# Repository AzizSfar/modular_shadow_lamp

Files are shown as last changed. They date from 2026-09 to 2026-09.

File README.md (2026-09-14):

# Modular shadow lamp

A wall lamp with a cylindrical or rectangular SVG-controlled optical sidewall, hollow LED pillar, removable cover, keyed stacking joints and a geometric wall-projection preview. The original default remains a 100 mm diameter, **30 mm closed-depth** cylinder.

**Start with `modular_shadow_lamp.scad`.** It contains an original sunburst demo and needs no external library. All dimensions are in millimetres. `OPTICS.md` contains the derivation, assumptions and limits.

## Try it in MakerWorld

1. Open [MakerWorld Parametric Model Maker](https://makerworld.com/en/makerlab/parametricModelMaker) and load the SCAD source.
2. Generate the built-in demo first. Default dimensions are diameter **100**, closed height **30**, shadow length **300**.
3. Choose **Projection** to see the ideal wall footprint, **Assembly** for the body and exploded cover, or **Diagnostics** for the numerical result.
4. To use your own SVG directly, set **Artwork_source = SVG file**, upload through **Svg_file**, and set **Svg_long_axis** to the longer *drawn artwork* axis. `resize()` normalises whichever axis you declare, so naming the shorter one scales the artwork up until the other axis overshoots the envelope every optical estimate assumes. A direct import is therefore **clamped to a `Shadow_length` square**: a correct declaration already fits and nothing changes, a wrong one is cropped on two sides with a straight edge. That crop is the symptom to look for, and Diagnostics states the clamp on screen. Monza is taller than wide, so `Y` is right — with `X` it would reach a 298 mm radius against a declared 212 mm, a 38% understatement that would make the feasibility numbers meaningless. The other dimension scales proportionally. The requested length is the full artwork's longest dimension before obstruction. The report and console identify the active artwork source.
5. Set **Smallest_detail_percent** to the smallest line or gap you need to preserve. Example: a 6 mm important detail in a 300 mm image is **2%**. Also enter your LED's effective emitting-area dimensions. These quantities materially affect feasibility.
6. Export **Body** and **Cover** separately, or use **Print layout**. Assembly, Projection and Diagnostics contain display geometry and are **not print exports**.

The `Svg_file = "default.svg";` file control follows [Bambu Lab's documented SVG-upload convention](https://forum.bambulab.com/t/paramatric-model-maker-v0-8-0-support-uploading-files/91853). The generator was rendered and tested locally with OpenSCAD 2021.01; its execution in your MakerWorld account has not been tested.

## Run locally — no MakerWorld required

On this computer, OpenSCAD is already available in `tools/openscad-2021.01/`.

- Double-click **Open lamp locally.cmd** to open the main generator in OpenSCAD.
- Double-click **Open SVG locally.cmd** to choose an SVG. It measures and embeds the artwork automatically, saves a fresh local SCAD file in `output/`, and opens it in OpenSCAD. This quick route skips the slow mesh preflight; run the full helper before printing.

In OpenSCAD, use its **Customizer** panel for dimensions and the **Output** selector. Use **Preview (F5)** after changes. For an STL, select **Body** or **Cover**, use **Render (F6)**, then export STL. If the preview reports an impossible combination, use the printed suggestions to adjust the dimensions.

To load an SVG directly without the helper, select **Artwork_source = SVG file**, enter its full path in **Svg_file** (forward slashes, for example `C:/Users/Aziz/Documents/design.svg`), and select the longer axis. **Automatic** mode recognizes changed file paths, while **SVG file** forces import even if the file is named `default.svg`. **Built-in demo** explicitly restores the sunburst.

The old generator needed `Use_svg = true`; uploading a file by itself could leave the demo selected. Its prepared examples also gave embedded artwork unconditional priority. The new selector fixes both cases and prevents old embedded support bridges from being applied to a replacement SVG. Reload the updated SCAD in MakerWorld to get the new controls.

The launcher needs Python 3 and OpenSCAD; both are already present here. On another computer, install OpenSCAD first. The helper's direct command also works locally:

```powershell
python run_local.py --svg "C:/path/to/artwork.svg"
```

## Automatic SVG preparation — recommended

For the Itachi and Monza reference investigation, see `DESIGN_REVIEW.md`. New
preparation controls and the dimension comparison tool are described below.

OpenSCAD imports SVG geometry but does not expose its dimensions, smallest feature or connected components to its scripting language. Consequently, direct MakerWorld mode requires the longer-axis selection and a declared minimum detail, and uses a conservative square envelope. **A pass in direct mode is not a complete SVG printability certificate.**

The included `prepare_svg.py` helper uses OpenSCAD itself to interpret the SVG, then:

- finds the actual drawn bounds and preserves the aspect ratio automatically;
- calculates a tighter outer-radius bound from the resulting polygons;
- embeds the artwork into a **single SCAD file** that can be uploaded to MakerWorld;
- checks the optical limits, exports the actual body mesh, and checks its edge closure and connectivity;
- adds short vertical ribs underneath disconnected stencil islands, rerenders and checks again;
- produces a checked body STL, cover STL and JSON report when successful.

From this project folder:

```powershell
python prepare_svg.py "C:/path/to/artwork.svg" --length 300 --diameter 100 --height 30 --detail-percent 2 --output output/my_lamp.scad
```

Python 3 and OpenSCAD are required. Default conversion uses the standard library; surface cleanup with `--minimum-web`, the design study and projection comparison also require NumPy and Pillow (already installed here). It finds the portable OpenSCAD in this project, an installed copy, or the executable given with `--openscad`. The distribution ZIP does not bundle OpenSCAD; [download it here](https://openscad.org/downloads.html) if needed.

The result is self-contained: upload `output/my_lamp.scad`. **Automatic** initially selects its embedded artwork. To replace it, select **Artwork_source = SVG file** and upload another SVG, or rerun the helper for automatic sizing and mesh checks. Dimension, source and support settings remain customizable. **Changing them after preflight invalidates the old mesh-check result; rerun the helper before printing the changed design.**

Try `examples/two_rings.svg` to exercise disconnected-island detection:

```powershell
python prepare_svg.py examples/two_rings.svg --output output/two_rings_lamp.scad
```

Use `--dark-silhouette` for filled SVG areas to remain dark within a circular lit field. By default, filled SVG areas become **light**, matching the luminous contour effect in the reference photograph. Convert strokes and text to paths, remove bitmap images and unwanted background rectangles, and inspect the imported result. OpenSCAD supports geometric SVG, not every SVG rendering effect; see its [SVG import documentation](https://files.openscad.org/documentation/manual/SVG_Import.html).

The helper deliberately does **not** invent a smallest-detail measurement: pointed corners mathematically taper to zero, and a minimum edge length is not a stroke width. `--detail-percent` is the detail you actually require. Automated bridges can change the appearance; inspect Projection after preparation.

## Reference preparation, fragile webs and housing shape

`Housing_shape = "Rectangle"` switches the body, cover, joints, standoff and wall
footprint together. `Rectangle_width` and `Rectangle_depth` are the two outer XY
dimensions. `Cylinder_height` remains the closed optical-module depth for either
shape. The wire pillar and its bore remain circular. Matching parts must share
the shape and both XY dimensions.

Use this preparation route for the supplied references:

```powershell
python prepare_svg.py itachi_example.svg --length 800 --diameter 80 --height 44 --wall-standoff 10 --minimum-web 0.6 --bridge-width 0.9 --automatic-bridges-only --output output/itachi_final.scad
python prepare_svg.py monza_example.svg --length 600 --diameter 80 --height 36 --wall-standoff 10 --minimum-web 0.6 --bridge-width 0.9 --automatic-bridges-only --output output/monza_final.scad
python prepare_svg.py monza_example.svg --shape Rectangle --rectangle-width 80 --rectangle-depth 80 --length 600 --height 36 --wall-standoff 10 --minimum-web 0.6 --automatic-bridges-only --output output/monza_rectangle_final.scad
```

These are **comparison prototypes**, using the existing 5% declared-detail
assumption and a 0.2 mm emitting area. Five percent is not a measurement of either
SVG's fine details. The new small-aperture screen reports features the 0.4 mm
filter flags; neither a broad optical pass nor mesh closure certifies that every
aperture will survive slicing with a 0.4 mm nozzle.

- `--automatic-bridges-only` starts without the twelve regular spokes. Mesh
  preflight adds vertical ribs only where needed and stops them inside each
  retained island. Projection includes the finite rib shadows.
- `--minimum-web 0.6` simplifies thin **opaque** slivers in developed inner-shell
  coordinates, sampled at about 0.06 mm. Corrections are projected back onto the
  wall and combined with the original vector light geometry. It does not thicken
  every stroke. Detached specks smaller than the width cubed (0.216 mm³ here)
  are removed through their projected footprints; larger islands receive ribs.
- `--bridge-width 0.9` is a starting point for approximately two extrusion lines
  with a 0.4 mm nozzle. Use your slicer's actual line-width settings. Simplification
  may erase dark detail; supports remove light. Check the comparison images.
- `--minimum-web 0` disables surface simplification. The default remains zero
  for compatibility. The native SCAD control uses a more conservative wall-space
  filter when no prepared surface stencil exists; its result is different.
- After changing geometry or artwork placement in a prepared surface file,
  rerun the helper. A stale prepared surface blocks Body/Print layout exports.
  Preview falls back to the native filter and warns; it is not a refreshed preflight.
- STL preflight welds export coincidences at 0.000001 mm and removes triangles
  collapsed by that rounding. This fixes export noise, not real disconnected parts.

Compare dimensions and actual artwork visibility:

```powershell
python compare_designs.py itachi_example.svg monza_example.svg --detail-percent 5 --output output/reference_study_5percent
python compare_designs.py itachi_example.svg monza_example.svg --detail-percent 2
python inspect_projection.py output/itachi_final.scad output/monza_final.scad output/monza_rectangle_final.scad --resolution 5000
```

The bounded study samples 4,320 combinations per reference: housing shape/size,
optical height, standoff, image length and XY placement. It counts the standoff
in **total depth**, and ranks `length / total depth / sqrt(footprint area) × visible
artwork fraction`, with an 85% visibility threshold. This is an explicit trade-off,
not a global optimum. Area retention does not know which parts of a character
are important. The 2% study demonstrates how much stricter detail requirements
can change the answer.

Projection inspection exports original artwork, housing-only clipping, the
modified footprint and an independent projection of the opaque STL. Its JSON
separates hidden artwork, removed light, added light and mesh/preview agreement.
Raster edge coverage affects the last metric, especially on narrow outlines.
Changing a generated source invalidates the stored mesh fingerprint.

## What the LED optimization means

The supported layout is a **concentric image surrounding the lamp**, as in the reference. The source is on the housing axis: **x = 0, y = 0**. This is the minimax position for a circular 360-degree field in the cylinder; the rectangle uses conservative on-axis bounds. The script analytically maximizes z subject to the upper collar, next module, pillar and source clearances. This is not an unrestricted optimizer for an asymmetric picture placed entirely beside the lamp.

The default demo gives:

| Quantity | Result |
|---|---:|
| Closed single-module depth | 30 mm |
| Body diameter | 100 mm |
| Emitting centre above module back | 24 mm |
| Printed pillar top | 21 mm |
| Ideal artwork length | 300 mm |
| Hidden central radius | 64.86 mm |
| Minimum local cut estimate, for declared 15 mm detail | 0.768 mm |
| Geometric source-blur estimate, 0.2 mm planar emitter | 0.425 mm |

The 0.2 mm emitter is an **optical assumption**, not a supplied or selected LED. Use the apparent emitting area seen through the side apertures; a domed lens may change it. A normal large or diffused LED may fail the sharpness limit. Zero source depth assumes a planar emitter parallel to the room wall. The LED must actually emit into the rays directed sideways and back toward the wall; a narrow forward-facing beam will not reproduce this preview.

The physical pillar prevents z=0, and the cover/next module prevents z=H. Manual-height mode reports incompatible positions instead of constructing a negative or colliding pedestal.

## Buildable versus worth printing

Two very different things used to share one verdict. They are now separate.

**Hard geometry** — a pillar wider than its cavity, a source below the floor, or an image that falls entirely inside the occluded centre — still refuses. There is nothing to build, and no warning rescues it. Diagnostics says *GENERATION NOT POSSIBLE: the geometry itself cannot be built*.

**Print quality** — the minimum cut width and the maximum blur — no longer blocks anything. The part builds, and Diagnostics reports *BUILDS — BELOW QUALITY LIMITS* in amber with the number that failed:

```
WARNING: this builds, but the smallest cut is 0.114 mm against a 0.4 mm minimum.
Blur is 2.76 mm against a 2 mm maximum. Fine detail will be lost or unprintable.
Try height 37 mm, shadow 363.4 mm.
```

`Quality_limits = "Refuse"` restores the old behaviour if you would rather be stopped. The helper carries the warning into its JSON report as `quality_warnings` and marks the validation string `BELOW QUALITY LIMITS`, so a preflight run tells you without refusing on your behalf.

This is a real choice, not a loosened check. A 0.114 mm slot will not print on a 0.4 mm nozzle — the detail closes up and you get a blob. The generator now assumes you would rather see the result and judge it yourself.

## Why some requests fail

“30 mm deep and a 1 m image” is not intrinsically impossible. It depends on diameter, feature size, source extent and image placement. Height alone cannot fix blur from a source that is too wide.

For example, with the **direct-SVG square envelope**, 100 mm diameter, 30 mm height, 1,000 mm length, 5% detail, 0.4 mm minimum cuts, 0.2 mm planar emitter and 2 mm maximum blur, the requirements fail. Diagnostics shows:

- an alternative shadow length at the same height;
- an alternative height at the same length, if one exists;
- a compromise minimizing the sum of the squared *relative* height and length changes.

The compromise searches larger heights in 1 mm steps up to the displayed limit (at most 300 mm), with a binary search for shadow length at each height. These are **nearest sampled alternatives under that stated metric**, not a claim of the globally closest dimensions. A conservative direct-import failure may disappear after the helper measures the actual SVG envelope. Suggested results do not establish brightness or physical printability.

For that example, the calculated compromise is **37 mm height / 371.9 mm shadow**. Keeping 30 mm height gives **287.9 mm shadow**. No tested height preserves the 1,000 mm request with the assumed emitter and 2 mm blur limit. Direct SVG mode's conservative bound also means a 300 mm request with the default 5% detail narrowly fails; start at **280 mm** or use the helper's tighter artwork measurement.

For the prepared **two-ring SVG**, the actual outer radius is smaller than the square bound. Requesting the same 1,000 mm length at 30 mm depth instead gives a **36 mm / 719.9 mm** compromise, **575.9 mm** at the original height, or **48 mm height** to retain the full 1,000 mm length under the selected optical limits. These are optical suggestions; rerun mesh preflight at the chosen dimensions.

## Cover, mounting and stacking

The wall is the XY plane at z=0; positive z points into the room. The wall-facing back has two keyholes with 7 mm head entries, 3.5 mm shaft slots and 5 mm upward slots. With the screw heads through the larger entries, slide the lamp downward to engage the narrow slots. Use a fastener and wall fixing appropriate to the actual wall and load.

The back is 4.5 mm thick, with a recessed keyed female socket. The front has the matching male tongue. The cover carries the same female socket. The default fit has **0.2 mm radial clearance** and **0.2 mm axial clearance**. This is a locating slip fit; use the three optional retaining screws when a positive hold is needed. The pilot-hole diameter is 2.1 mm; select and test compatible short screws. The fit and screw choice have not been physically tested.

The closed 30 mm assembly includes a 4.5 mm cover. Remove it and seat the next cylinder onto the tongue. Each added module increases the depth by **25.5 mm**. Two modules plus one final cover are 55.5 mm deep. Keep diameter, wall, joint and cover dimensions the same across a stack.

Generate each optical cylinder for its own **Module_index**: 0 at the wall, 1 next, and so forth. Every optical module needs its own LED at its own calculated height. The solid rear floor separates the modules. Moving a cylinder farther from the wall without regenerating it changes its projection. The central obscured area grows for farther modules; increasing the target length may be necessary. Stack preview displays the selected module's light and simplified lower-module envelopes, not a summed multi-LED lighting simulation.

The pillar contains a wire bore and terminates 3 mm below the nominal emitting centre. It is a generic mounting land, not a fit for an unspecified LED package. Attach an LED carrier whose **optical centre** has the stated offset. Larger boards, wiring, screw heads or electronics entering the optical rays can create additional shadows. The cover opens the electronics compartment; electrical design, heatsinking and thermal testing remain to be done with the actual hardware. Keep retaining holes occupied or plugged during optical tests.

## Wall standoff and the electronics compartment

`Wall_standoff` is the clear gap held between the room wall and this module's back. **0 is flush to the wall and reproduces the previous geometry exactly.** The gap is a closed compartment with the keyholes and cable route on its own back plate, whose thickness is `Standoff_back`.

- **Separate ring** (`Output = "Standoff"`) prints the gap as its own part, driving the same keyed tongue into the body's existing rear socket. Change the standoff without reprinting the optical body. Needs `Wall_standoff >= Standoff_back`.
- **Extended body** grows the body backwards instead: one part, no extra joint, but any change means reprinting the whole optical body.

Optically, a standoff is identical to mounting the module further into the room. Every mechanical plane translates with it, so the source rises by exactly the standoff and radial resolution improves in direct proportion. **It is not free.** `rho_dead = R*h/(h-A)` has both `h` and `A` rising together, so the hidden centre widens at a similar rate:

| Standoff | Source height | Cut estimate | Hidden radius |
|---:|---:|---:|---:|
| 0 mm | 24 mm | 0.768 mm | 64.9 mm |
| 20 mm | 44 mm | 1.408 mm | 118.9 mm |
| 50 mm | 74 mm | 2.368 mm | 200.0 mm |

So a standoff pays off only if the image grows with it. On the default 100 × 30 mm module, 50 mm of standoff **rejects** a 300 mm image — the 200 mm dead radius swallows it — while projecting 600 mm comfortably at a 1.184 mm cut estimate. Flush, the same lamp cannot reach 600 mm at all and manages 300 mm at 0.768 mm. Read the Diagnostics suggestion when it refuses.

From the helper:

```powershell
python prepare_svg.py artwork.svg --wall-standoff 25 --length 500 --output output/my_lamp.scad
```

The ring is mesh-checked alongside the body and cover and written to `<name>_standoff.stl`.

The compartment is a void with a cable route, nothing more. Electrical design, insulation, driver placement, clearances and heat inside it are yours to work out, and none of it has been tested.

## Bounding the light in dark silhouette

By default a dark silhouette sits in a lit disc that reaches the whole beam radius. **Light limit** replaces that disc with a band of chosen width hugging the shadow; past the band the wall goes dark again.

```
Artwork_mode          = "Dark silhouette";
Light_limit           = true;
Light_limit_shape     = "Same as shadow";   // or Circle, Rectangle
Light_limit_thickness = 25;                 // band width on the WALL, mm
```

- **Same as shadow** follows the outline, offset outwards by the thickness. Corners come out rounded at the band radius; a mitred outset would spike at acute corners into slivers too fine to print.
- **Circle** wraps the artwork's bounding circle. Note this is *larger* than the unlimited disc whenever the thickness exceeds `Dark_field_border`, so it is a way to size the lit disc explicitly rather than a way to shrink it.
- **Rectangle** wraps the artwork's true bounding box, and turns with `Artwork_rotation` so it stays tight. The real proportions can only be measured by the helper — a directly imported SVG falls back to a square, which for a tall or wide design lights a lot of empty wall. A rectangle also reaches furthest at its **corners**, so its optical envelope is `sqrt(2)` times a circle of the same half-width and it fails the feasibility test sooner.

From the helper:

```powershell
python prepare_svg.py artwork.svg --dark-silhouette --light-limit --light-limit-thickness 22 --light-limit-shape "Same as shadow" --output output/my_lamp.scad
```

### Which side of the artwork gets bounded

`offset()` moves every boundary at once, so on a closed outline — a circuit map, a monogram, any loop — it eats the enclosed interior as well as bounding the outside. The two sides are therefore separate switches:

```
Light_limit_outside = true;   // bound the light outside the artwork's silhouette
Light_limit_inside  = false;  // leave an enclosed interior fully lit
```

For a circuit map that combination is almost always what you want: a band tracing the outside of the track, and the whole infield lit. All four combinations are legal — `outside off / inside on` lights the entire beam except a ring inside the loop, which is the inverse effect.

**`Light_limit_inside` works on any artwork, with nothing else to configure.** Splitting the field needs to know which enclosed areas are interior. Prepared artwork carries a measured silhouette; a direct import — including every MakerWorld upload, where the helper cannot run — has none, so the interior is found by closing anything narrower than `Interior_span`.

`Interior_span = 0` means **automatic, and automatic is `Shadow_length`**. An enclosed area cannot be wider than the artwork that encloses it, so that is the one value which can never under-fill. Set a smaller number only if you want a tighter result: too small silently finds nothing, which is the failure this default exists to prevent. Diagnostics names the method — measured silhouette, or closed at N mm, marked *(automatic)* or *(set)* — so you never have to guess whether it took effect.

Artwork prepared by the helper needs none of that: it carries a measured **silhouette** and ignores `Interior_span` entirely. Telling a hole from the outside needs the artwork's **silhouette** — its outermost contours with every hole filled. Only the helper can work that out, by testing the nesting depth of each flattened contour, so it writes the silhouette into the file as separate geometry. A directly uploaded SVG has none, and the generator then applies one setting to both sides and echoes a note saying why. Use `--light-limit-inside off` / `--light-limit-outside off` on the helper.

### Two things the band does to you

**A thin band is a thin slot.** Unlike `Smallest_detail_percent`, which you declare, the band width is a feature the generator knows exactly, so it reports the slot the band opens in the shell and warns when that falls under `Minimum_cut_width`. Flush, 300 mm image:

| Band | Slot in the shell |
|---:|---|
| 5 mm | 0.240 mm — warned |
| 10 mm | 0.450 mm |
| 25 mm | 0.940 mm |
| 50 mm | 1.440 mm |

The minimum that clears a 0.4 mm slot is **8.8 mm** flush at 300 mm, **4.5 mm** with a 20 mm standoff, **10.9 mm** at 50 mm standoff / 600 mm — roughly 2–3% of image length, and a standoff nearly halves it. A band under the limit still builds, with the warning and the suggested width in Diagnostics, so you can preview something you know is too fine to print.

**A closed band strands whatever it encircles.** Every shape inside a loop of light is disconnected from the frame. This is not new — an unlimited dark silhouette does exactly the same, and the mesh preflight measures the identical component count either way — but it means `Support_bridges` or the helper's automatic ribs must stay on, and their lines will cross the band. A narrower band means shorter, less obtrusive bridges.

One behaviour worth watching: widening the band fuses the halos of nearby shapes into one. On `two_rings` at 160 mm, 3/8/20 mm bands keep four separate lit regions and a 40 mm band drops to three. Nothing warns about this — inspect Projection after changing the thickness.

## Print and physical test

Print the body with its flat rear face on the bed. The Cover output is already flipped with its solid face on the bed. Preview the sloped apertures and small underside socket bridges in your slicer; support requirements depend on the artwork and printer. Use opaque material and remove any support that blocks the optical tunnels. Print a joint-fit sample or check the first module before producing a stack.

First test at the calculated LED position on a wall in a dark room. Measure image length, adjust the source to the *emitting centre*, and compare detail sharpness. The preview is an ideal geometric light footprint, not a prediction of brightness, colour, scattering, lens effects or diffraction. The lamp inevitably hides the centre; no sidewall pattern can recover artwork behind its opaque body. Narrow connecting bridges also cast dark lines. Exact reproduction of an arbitrary, unmodified SVG is therefore not always physically possible with this architecture.

## Validation supplied

`output/validation.json` records checks on the default exported body and cover. Both have one connected surface component and every mesh edge belongs to two triangles. An independent perspective projection of the opaque STL triangles agrees with the analytic footprint with intersection-over-union **0.9864** at 2,000 × 2,000 pixels over a 360 mm wall field. Raster edge coverage accounts for much of the residual difference; this is not a physical optical test.

`tests/test_optics.py` checks inverse/forward ray mapping through both shell radii, finite-difference surface compression and source blur, stacked-module offsets, invalid source cases and a suggested dimension pair. `tests/verify_mesh_projection.py` additionally requires NumPy and Pillow. The helper's SVG test checks the exported stencil and adds two retaining bridges to the supplied two-ring example.

`tests/check_joint_fit.py` checks the actual body against a seated cover, a following body, and a seated standoff ring. All three intersections are empty after a 0.01 mm separation to exclude intended coplanar seating contact; the default parts have no positive-volume interference in this test.

`tests/test_light_limit.py` covers the light limit: that switching it off changes nothing, that a band lights less wall than the unlimited disc, that the band is exactly the artwork grown by the thickness minus the artwork, that each shape reaches as far as its geometry predicts and a rectangle's envelope uses its corner rather than its side, that the reported slot scales with the band and the suggested minimum really clears the limit, that a band too fine to print warns and still builds, and that the band strands exactly the same number of islands as the unlimited disc already did.

`tests/test_standoff.py` covers the standoff against real rendered meshes: that the source rises by exactly the standoff while the local height is untouched, that sharper detail and a wider hidden centre move together across 0/20/50 mm, that 600 mm is reachable at 50 mm of standoff and not at 0, that 50 mm of standoff correctly *refuses* a 300 mm image, that a zero standoff leaves the body identical, that the ring and both body modes are single closed solids sitting on the bed, and that the compartment is a vented shell rather than a sealed cavity. A ring thinner than its own back plate, and a Standoff export with no ring configured, are checked to fail loudly.

No physical lamp has been printed or illuminated yet. Mesh closure does not prove minimum ligament thickness, support-free printing, mechanical strength, thermal performance or an exact match to the photograph.

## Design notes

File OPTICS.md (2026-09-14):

# Projection geometry and optimization

All distances below are millimetres. These equations are derived for straight rays, an opaque cylinder and a point source. Finite-source estimates are a first-order extension; the display itself uses the point-source footprint.

## 1. Coordinate system and the inverse construction

The room wall is z=0. The cylinder axis is normal to it. Let the source be S=(0,0,h), with h measured **from the room wall**, and let a desired lit wall point be P=(x,y,0), with radial distance rho=sqrt(x²+y²).

The complete ray is

```
Q(t) = S + t(P-S),       0 <= t <= 1.
```

At a cylindrical surface of radius r, t=r/rho. Therefore:

```
Q_r(P) = (r*x/rho, r*y/rho, h*(1-r/rho)).
z_r    = h*(1-r/rho).
```

The outer surface is crossed at z_o=h(1-R/rho), and the inner surface at z_i=h(1-R_i/rho). Since R_i<R, z_i>z_o. **The inner and outer openings must be at different heights.** Simply wrapping the SVG around the cylinder, or making straight radial holes, does not implement the correct projection through a thick shell.

The forward check is:

```
P_xy = h/(h-z) * Q_xy.
rho  = h*r/(h-z).
```

For every filled 2D target point, `linear_extrude()` with a linearly decreasing scale sweeps precisely this ray. The script subtracts that entire perspective cone from the shell. It ends the cone 0.05 mm below the source, with scale 0.05/h, avoiding a degenerate apex while leaving the optical shell intersections unchanged. All valid source clearances keep the shell crossings below that truncated tip.

The approach uses OpenSCAD's [linear extrusion with scale](https://files.openscad.org/documentation/manual/OpenSCAD_User_Manual.pdf) and [SVG geometry import](https://files.openscad.org/documentation/manual/SVG_Import.html). The equations and feasibility policy here are specific to this project.

## 2. Mechanical planes and the hidden centre

Let H be one closed module's depth, J the tongue insertion depth, T the cover plate thickness and p=H-J-T the stacking pitch. For module n:

```
z0 = S + n*p                     module back's distance from wall
A  = z0 + rear_floor + rear_guard lower optical opening limit
B  = z0 + p - front_guard         upper optical opening limit
R_f = R - frame_width            thick front collar's inner radius
```

S is the wall standoff: the clear gap held between the room wall and module 0's back,
by a separate spacer ring or by an extended rear skirt on the body. It enters every plane
above, so optically a standoff is indistinguishable from mounting the same module that
much further into the room.

A ray must cross the outer radius above A. Thus

```
h*(1-R/rho) >= A
rho >= R*h/(h-A),                 with h>A.
```

This is larger than R: the rear plate and uncut structural rim hide more than just the visible body diameter.

The pillar is modelled as a cylinder of radius r_p ending e below the emitting centre. Its upper edge creates another central shadow:

```
rho_pillar = r_p*h/e.
rho_dead   = max(R*h/(h-A), r_p*h/e).
```

Both expressions use **absolute h**, including the stacking offset. They explain why farther modules hide a larger central portion of the wall. The source cannot be put on the wall plane: the forward mapping degenerates at h=0 and the hardware occupies that space.

If h>B, the front collar sets an outer reach:

```
rho <= R_f*h/(h-B).
```

If h<=B, this upper-collar limit is absent because all rays heading toward the wall are below the collar. The sidewall's upper opening gives the same form with R_i; R_f is smaller and therefore more restrictive in this design.

The displayed light is the intended 2D transmitting region intersected with this reachable annulus, minus the radial support wedges. The cylinder itself overlays the central body disk in the display. Mounting holes sit behind that disk; other electronics are not represented as occluders.

## 3. Why x=y=0 for the supported layout

The objective is to maximize the **worst local reproduction scale over a complete concentric 360-degree field**, not to fit a spotlight image displaced to one side. The pillar moves with the source in the hypothetical comparison, and the housing remains concentric.

For a lateral displacement d, look at the two wall directions parallel and opposite to the displacement at the same radius rho. The radial stretch coefficients are proportional to:

```
g_near = (R_i-d)/(rho-d)^2
g_far  = (R_i+d)/(rho+d)^2
g_axis = R_i/rho^2.
```

For both displaced coefficients to exceed g_axis would require both

```
rho*(2*R_i-rho) > R_i*d
rho*(rho-2*R_i) > R_i*d,
```

which is impossible for d>0. At least one radial direction gets worse. The tangential stretch toward the nearer side, (R_i-d)/(rho-d), is also smaller than R_i/rho when rho>R_i. Therefore a displaced source cannot improve the worst of the radial and tangential stretches around the full circle at fixed h. The nearest-side upper-collar clearance also cannot allow a larger h than the concentric source, and the mechanical ceiling is unchanged.

This establishes the on-axis minimax choice for that symmetric field. An asymmetric SVG occupying only a restricted angular sector could benefit from an off-axis source. Such an artwork-specific, unrestricted optimization is **outside this generator's scope**; setting x and y to zero must not be interpreted as having performed it.

## 4. Height optimization

Let rho_max=k*L bound the artwork, where L is its longest dimension. Direct SVG mode uses k=sqrt(2)/2, which bounds a centred square of side L. The helper evaluates k=max(sqrt(x_i²+y_i²)) over the normalized polygon vertices. A convex norm attains its maximum on each straight polygon edge at an endpoint, so this is a valid bound for OpenSCAD's flattened geometry. The demo has k=1/2.

The source must clear the **back of a possible next module**, rather than borrowing cavity space inside the removable cover:

```
h_ceiling = z0 + p - 1.5.
```

To reach rho_max through the front collar:

```
h <= B/(1-R_f/rho_max),           when rho_max>R_f.
```

To leave at least some possible artwork beyond the pillar shadow along the longest dimension:

```
h <= e*(L/2 - minimum_cut - epsilon)/r_p.
```

The selected h is the minimum of those upper bounds. The code subsequently checks the lower hardware and rear-rim clearances. Within these constraints, larger h increases radial aperture size, improves axial-source blur and reduces the rear-rim shadow. The explicit pillar constraint prevents increasing h until its shadow swallows the whole field.

This maximizes the local resolution estimate for the supported field. It is not an optimization of total luminous flux, subjective image quality, occluded image area or manufacturing cost. If the SVG has no filled region in the reachable annulus, the envelope test alone cannot detect that; the helper's geometry/mesh inspection and the preview remain necessary.

## 5. How detail compresses onto the shell

Parameterize the inner shell by arc length s=R_i*theta and height z=h(1-R_i/rho). A tangential wall displacement rho*dtheta becomes R_i*dtheta, and a radial displacement d(rho) becomes (h*R_i/rho²)*d(rho). The local scale factors are:

```
sigma_t = R_i/rho
sigma_r = h*R_i/rho^2
sigma_min = min(sigma_t, sigma_r).
```

For a declared important wall detail f=alpha*L, use the conservative outer-radius estimate:

```
w_estimate = f * min(R_i/rho_max, h*R_i/rho_max^2).
```

The radial direction is often much worse than the tangential one. At constant fractional detail alpha and envelope k, radial cut size varies approximately as h/L. Merely making the requested wall image bigger does not make it easier to print.

For h=24, R_i=48, rho_max=150 and f=15, the estimate is 0.768 mm. For the direct square bound of a 1,000 mm image, rho_max=707.107 and f=50, it is about 0.115 mm: below a selected 0.4 mm cut limit.

### 5a. What a standoff buys, and what it costs

Raising the module by S raises the admissible source height by very nearly S: the collar
constraint h = B/(1-R_f/rho_max) is linear in B, and B grows with S. sigma_r = h*R_i/rho_max^2
is linear in h, so radial resolution improves in direct proportion.

The hidden centre moves the other way. In rho_dead = R*h/(h-A) both h and A grow by S, so the
numerator grows while the denominator barely moves and the occluded disc widens roughly
linearly in S. Measured on the default 100 x 30 mm module at L=300:

| Standoff S | Source h | Cut estimate | Hidden radius |
|---:|---:|---:|---:|
| 0 mm | 24 mm | 0.768 mm | 64.9 mm |
| 20 mm | 44 mm | 1.408 mm | 118.9 mm |
| 50 mm | 74 mm | 2.368 mm | 200.0 mm |

A standoff therefore does not simply make images bigger: it trades a wider dead centre for
sharper detail, a net gain only if the image grows with it. At S=50 the feasibility test
L/2 > rho_dead + w_min fails outright for L=300, while L=600 passes with a 1.184 mm cut
estimate -- a length the flush module cannot reach at all.

This is a **local first-order feature estimate**, not an exact minimum-thickness computation on every curve, ligament or oblique channel. Sharp tips naturally approach zero width. What counts as an important feature must be specified by the designer. The helper detects disconnected components but does not certify every ligament's width or printer capability.

### 5c. A bounded lit field

A dark silhouette normally subtracts the artwork from a disc of radius k*L + border. The
light limit replaces that disc with a bounded region D, so the lit field is D minus the
artwork. Three choices of D:

```
Same as shadow:  D = artwork (+) disk(T)        rho_max = k*L + T
Circle:          D = disk(k*L + T)              rho_max = k*L + T
Rectangle:       D = box(w*L/2 + T, h*L/2 + T)  rho_max = hypot(w*L/2 + T, h*L/2 + T)
```

where (+) is Minkowski addition, w and h are the artwork's extents as fractions of its
longest side, and T is the band width on the wall. The rectangle reaches furthest at its
corner, which is what rho_max must use; taking its half-width instead understates the
envelope by up to sqrt(2) and lets an infeasible request pass.

The band width is the one wall feature whose size is known rather than declared, so its
slot in the shell follows directly from section 5:

```
w_band = T * min(R_i/rho_max, h*R_i/rho_max^2).
```

Since rho_max itself contains T, the thinnest band that still opens a w_min slot has no
closed form; the generator settles it by repeated substitution. At h=24, R_i=48, k=0.5 and
L=300 the fixed point is T = 8.8 mm for w_min = 0.4 mm. A standoff raises h and so lowers
that floor: 4.5 mm at S=20.

### 5d. Bounding one side of a closed outline

Minkowski addition moves every boundary of A outwards, which for a hole means inwards. On a
closed outline the enclosed interior is a hole, so `A (+) disk(T)` shrinks it by T and the
interior goes dark. Bounding the outside without touching the inside needs the silhouette

```
F = fill(A),   A's outermost contours with every hole filled,
```

and then the field splits at F:

```
outside = (disk(beam) - F)  intersect  (bounded ? D : everything)
inside  = F                 intersect  (bounded ? A (+) disk(T) : everything)
D_total = outside union inside,     lit = D_total - A.
```

All four on/off combinations fall out of this, and both switches off reproduce the plain
dark silhouette exactly. fill(A) is not obtainable from A by morphology -- a closing fills
holes only up to its own radius and rounds everything else on the way -- so it comes from
contour topology instead: flatten the SVG, count how many contours of the same path contain
each contour, and keep those at even-odd depth zero. That is a property of the path data, not
of the rendered region, so it is available to the preparation helper and not to `import()`.

When the silhouette cannot be measured -- a direct `import()`, and so every MakerWorld
upload -- fill(A) is approximated by a morphological closing with a mitred structuring
element of half-width S:

```
fill(A) ~= erode(dilate(A, S), S).
```

Dilation followed by erosion returns a convex boundary to where it started and closes any
enclosed area or concave pocket narrower than 2S, so the error is confined to outer pockets
narrower than the span. Measured against the exact silhouette of the Monza outline at
L=300 mm, where the true fill is 19,304 mm^2:

| S | closing | missing | extra | error |
|---:|---:|---:|---:|---:|
| 40 mm | 7,800 | 11,573 | 69 | 60.3% |
| 60 mm | 19,420 | 2 | 117 | 0.62% |
| 120 mm | 19,509 | 3 | 208 | 1.10% |
| 200 mm | 19,308 | 141 | 144 | 1.48% |
| 450 mm | 21,882 | 8 | 2,586 | 13.4% |

The usable window is broad: anything from just over half the enclosed width up to roughly the
artwork's own length agrees with the exact silhouette to within about 1.5%. Below that it
under-fills sharply, and far above it the result drifts toward the convex hull, which for this
outline is 28,628 mm^2. Rounded joins were rejected: `offset(r=)` pulls the outer boundary in
during erosion, whereas mitred joins restore it exactly.

The construction says nothing about connectivity. D minus artwork is an annular region
whenever the artwork lies inside D, so every enclosed shape is a separate component of the
opaque stencil. That is already true of the unbounded disc and is not made worse here, but
it is structural rather than incidental: no choice of T avoids it.

## 6. Finite LED size and blur

At a fixed aperture point (Q_xy,z), the wall point from a source with transverse location S_xy is

```
P_xy = S_xy + h/(h-z)*(Q_xy-S_xy).
M = h/(h-z) = rho/R_i.
```

Differentiate with respect to the source position while holding the aperture fixed:

```
|dP/dS_xy| = M-1
|dP/dh|   = (M-1)*rho/h.
```

For effective transverse source diameter d_xy and axial extent d_z, the sum

```
b_estimate = (rho_max/R_i - 1) * (d_xy + d_z*rho_max/h)
```

is a conservative first-order extent estimate. Axial thickness is especially costly at grazing angles. With a planar source, transverse blur is independent of h at fixed cylinder and image radii: a taller cylinder alone cannot fix an overly wide source. Lens optics, angular emission, vignetting, scattering and diffraction are not simulated. A finite source also shifts the effective aperture visibility, so this scalar estimate is not a rendered penumbra.

For illustration, an isotropic point source of radiant intensity I produces wall irradiance

```
E(rho) = I*h/(rho^2+h^2)^(3/2).
```

The extra cosine factor from the grazing wall angle means far-wall brightness falls approximately as rho^-3 in this shallow geometry. A wall-facing Lambertian emitter adds another cosine factor. Without the LED's angular intensity distribution and power, the script cannot infer usable brightness or exposure.

## 7. Feasibility and closest alternatives

The solver requires valid mechanical dimensions, a valid source position, some potential field outside the central obstruction, the local cut estimate above the chosen threshold, and estimated blur below the chosen maximum. It does not invent a universal maximum image size from cylinder height alone.

On failure in automatic mode, it searches H upward in 1 mm steps to min(300,max(160,3*H_requested)). At each height it finds the largest qualifying L no greater than the requested length, using a binary search on the monotone quality limits, followed by the mechanical/visible-field checks. It rounds L downward to 0.1 mm. Candidate pairs minimize

```
cost = ((H-H_requested)/H_requested)^2
     + ((L-L_requested)/L_requested)^2.
```

Equal relative changes have equal weight. The script additionally reports holding the requested H fixed or holding L fixed. If no candidate exists, it states that the selected search range/assumptions have no solution and suggests changing diameter, required detail or source extent. It does not label that as a proof of physical impossibility under all possible designs.

## 8. Structural and optical compromises

Closed luminous outlines can leave opaque material floating inside an opening. Fixed spokes cannot retain every arbitrary island. The helper exports the real body and identifies disconnected surface components. It now places vertical ribs under the lowest face of each substantial floating component, stopping inside the island. With surface cleanup enabled, detached specks below `Minimum_web_width^3` cubic millimetres are removed through their projected convex footprints and recorded explicitly in the JSON. It rerenders and checks again, up to eight attempts. Unresolved failures are reported.

Connectivity does not establish ligament strength or physical printability. Bridges necessarily alter the original light pattern. A fully exact SVG containing floating opaque islands needs another support architecture, such as a separate transparent mask substrate, and cannot be promised by a single-material carved shell.

Stacking adds an absolute offset to every ray calculation. Equal-diameter lower modules are behind the current module's rear plate and within its central occlusion envelope. Larger lower modules, external brackets, exposed electronics and light leakage through open cable/screw holes require additional occlusion modelling. Generate each equal-diameter module for its own index and use independent, properly shielded sources.

## 9. Rectangular housing and bounded design study

The cone remains `P(t) = (t*x, t*y, h*(1-t))`; only the housing intersection
changes. For a face at X=a, a wall point (x,y) maps to `(a, a*y/x, h*(1-a/x))`.
The inverse is the same perspective projection as for the cylinder. Flat faces
introduce shear, so using only radial and tangential cylindrical scales would
overstate the rectangular worst-direction resolution.

For the face map `(x,y) -> (a*y/x, h*(1-a/x))`,
`|det J| / ||J||F = a*h/(|x|*sqrt(x*x+y*y+h*h))` is a lower bound on the least
singular value. The implementation conservatively substitutes the minimum inner
face distance for a and the maximum artwork radius for |x| and hypot(x,y).
The upper-collar/source bound and blur estimate use the minimum inner radius.
These are conservative envelope bounds, not an artwork-specific flat-face optimum.

The lower aperture obstruction is the **actual outer footprint**, scaled by
`h/(h-bottom_absolute)`, combined with the circular pillar obstruction. The
upper clipping footprint uses the inset front collar. The reported rectangular
dead radius is a corner envelope; the preview does not black out that full circle.
Joints and cover use the same rectangular inset profiles as the body.

The standoff enters `off(H) = standoff + module_index*pitch` and the cone origin,
source, lower and upper aperture planes, body placement and projection. Its
integration was already correct. The stack display now also offsets lower
module envelopes by the standoff.

For a fixed total depth, transferring depth from standoff to optical body lowers
the absolute rear aperture while keeping the ceiling nearly fixed. It can shrink
the hidden centre markedly. Thus optimizing body height alone encourages an
unhelpfully tall standoff. `compare_designs.py` counts **body height + standoff**
and measures filled-SVG area outside the actual footprint. It samples a declared
finite grid and ranks an explicit compactness/visibility score. Neither the
score nor the 85% area threshold proves an artistic or global optimum.

## 10. Developed-surface preparation and verification

`--minimum-web` samples light on the developed inner shell at approximately
0.06 mm pitch, wraps around the seam, and closes narrow opaque slivers there.
Rectangle faces unroll with their physical perimeter lengths. Only correction
regions, with one cell of overlap, are mapped back to wall coordinates. The
original vector light is retained. A small 0.01 mm wall-space closing removes
numerical tangencies before oblique extrusion. These operations simplify dark
detail instead of shrinking every bright contour by a worst-case global offset.

Finite ribs extend from the rear collar to their stored local Z. Their maximum
wall extent is the outer footprint scaled by `h/(h-off-z_top)` (including the
small Boolean overlap). This keeps the preview consistent with their truncated
height rather than displaying full-length spokes.

Opening the sampled light mask with a 0.4 mm kernel provides a **small-feature
screen**, reported as a fraction of inner-shell light area. Corners contribute to
that fraction; it is not an exact stroke-width measurement, lost-wall area or a
slicer prediction. The user confirmed a 0.4 mm nozzle. A 0.9 mm rib is a useful
starting point for two roughly 0.45 mm extrusion lines, consistent with
[Prusa's line-width guidance](https://help.prusa3d.com/article/layers-and-perimeters_1748).
Actual line width, layer height, material, overhangs and the LED still need testing.

The surface filter cannot certify minimum neck thickness, self-supporting layers
or mechanical strength. Connectivity is checked on the final mesh. Export-only
coincident vertices are welded at 0.000001 mm, with collapsed triangles removed;
the mesh is then required to have exactly two incident triangles per edge and
one connected surface. This tiny numerical cleanup is separate from deliberate
removal of small stencil specks.

`inspect_projection.py` translates STL vertices by the actual body wall offset
before projecting opaque triangles. It supports both housings, stacked modules
and both standoff modes. It reports original-area retention, added light,
support/clipping loss, and STL/analytic intersection-over-union separately.
Narrow outlines are sensitive to raster edge coverage; inspect the images and
record resolution alongside the numerical agreement.

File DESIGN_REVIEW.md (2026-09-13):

# Reference design review — 2026-09-13

The best direction within the tested carved-shell designs is **a cylinder with a
modest standoff and a larger share of its depth assigned to the optical body**.
Making the optical section very shallow and compensating with a tall electronics
chamber hides too much of the image. A rectangle is now available for comparison,
but it did not improve Monza's visibility at the same outer width and total depth.

## Prepared comparison prototypes

| Reference | Housing XY | Optical body + standoff | Artwork length | Original filled area retained | STL / preview agreement |
|---|---|---|---|---|---|
| Itachi | Ø80 mm | 44 + 10 = **54 mm** | **800 mm** | **88.39%** | **99.02%** at 5,000 px |
| Monza | Ø80 mm | 36 + 10 = **46 mm** | **600 mm** | **97.25%** | **97.84%** at 10,000 px |
| Monza rectangle | 80 × 80 mm | 36 + 10 = **46 mm** | **600 mm** | **94.69%** | **97.95%** at 10,000 px |

The respective files are `output/itachi_final.scad`, `output/monza_final.scad`
and `output/monza_rectangle_final.scad`. Each has a body STL, cover STL, standoff
STL and JSON report. Each final part has one connected surface and two triangles
incident on every mesh edge. The rectangular body, cover and standoff joints were
also checked for positive-volume interference using a non-square 60 × 90 mm case.

These are candidates from a bounded study, not globally optimal dimensions or
print-certified parts. The electronics have not been measured to fit the 10 mm
compartment. The user confirmed a **0.4 mm nozzle**; the **0.2 mm emitting area**
is still only the original project's optical assumption. A larger emitter can
invalidate the sharpness estimates.

The candidates use the original **5% declared-detail** requirement: 40 mm at an
800 mm image, or 30 mm at 600 mm. That does **not** certify the SVG's smaller
features. Repeating the bounded study at 2% finds no Itachi candidate retaining
85% of the artwork, and only a few substantially deeper Monza candidates. The
fine detail requirement is therefore a real design constraint, not a checkbox
that the optimizer can infer from the filename.

## What changed

1. **Standoff and size comparison.** The standoff was already present in the
   inverse rays, source height and wall clipping. The new study varies standoff,
   optical height, XY size, image length and image placement, counts total depth,
   and measures actual filled-SVG visibility. It samples 4,320 combinations for
   each reference. The stack display's lower envelopes now include the standoff.
2. **Rectangular option.** Body, removable cover, mating joints, standoff and
   projection all use the selected footprint. Width and depth can differ. Flat
   faces use a conservative shear-aware compression estimate.
3. **Fragile opaque slivers.** Optional preparation works in physical developed
   shell coordinates, rather than expanding every wall-space stroke by the
   worst-case magnification. It selectively removes tiny dark strips. This is
   a controlled simplification; it does not preserve every dark detail exactly.
4. **Floating islands.** Automatic-only mode removes the blanket twelve spokes.
   Sub-print-size detached specks are removed and reported; larger pieces get
   short 0.9 mm vertical ribs beneath them. Itachi needed eight ribs and removal
   of four tiny specks. Both final Monza versions needed no additional ribs.
5. **Verification.** The helper checks final mesh closure/connectivity, fixes
   collapsed STL export triangles at 0.000001 mm precision, and records a source
   fingerprint. A prepared surface stencil refuses a body export after relevant
   geometry edits until regenerated. Independent STL projection is compared
   with the preview, including the standoff and truncated supports.

## Shadow changes and remaining print questions

The 30 mm body + 30 mm standoff Itachi trial at 600 mm hid about 49% of the original
filled artwork before supports. The 44 + 10 mm candidate at 800 mm hides about
10% before supports, while being 6 mm shallower overall. This is why minimizing
only the optical body height is misleading.

On the final Itachi candidate, cleanup introduces additional light equivalent
to **8.13%** of the otherwise visible light area and supports/cleanup remove
**1.68%**. Its visible-pattern intersection-over-union against the unmodified,
housing-clipped artwork is **90.93%**. The remaining central hole is inherent to
the opaque housing and pillar; it has not been fixed by modifying the SVG.

For Monza, added light is **3.91%** for the cylinder and **2.33%** for the rectangle;
visible-pattern agreement is **96.20%** and **97.71%**, respectively. The rectangle
changes less detail in this test but hides more of the track. At half the raster
resolution, STL agreement was about 96%; the increase to about 98% at 10,000 px
shows the sensitivity of these narrow outlines to raster boundary coverage.

The 0.4 mm small-aperture screen flags **0.98%** of Itachi's sampled inner-shell
light area, **12.60%** of Monza's and **13.36%** of rectangular Monza's. This includes
corners and is not a prediction that those exact percentages disappear in print.
It does mean that Monza's finest openings need close slicer inspection. The
filter does not certify minimum neck thickness, overhangs, layer-by-layer support,
strength, brightness, heat or physical joint fit.

For a 0.4 mm nozzle, the 0.9 mm ribs are a reasonable two-extrusion starting point
when line width is about 0.45 mm; use the actual slicer setting. See
[Prusa's perimeter guidance](https://help.prusa3d.com/article/layers-and-perimeters_1748).
Exact reproduction of arbitrary fine SVG detail with no opaque supports may
require a different mask construction, such as an opaque pattern carried by a
transparent substrate. That would still need optical and material testing.

## Files to inspect

- `output/reference_comparison.png`: compact overview of the three predicted patterns.
- `output/itachi_final_projection/comparison.png`: original, housing-only clipping,
  modified footprint and independent STL projection.
- `output/monza_final_projection/comparison.png`: the same comparison for Monza.
- `output/monza_rectangle_final_projection/comparison.png`: rectangular comparison.
- `output/reference_study_5percent/`: candidate CSVs and selected dimensions under
  the original declared-detail assumption.
- `output/reference_study/`: the stricter 2% study.
- `README.md`: commands for regeneration and the new controls.

Validation: **29 distinct automated tests passed**, including the existing
standoff/source cases, rectangular part closure and dimensions, rectangular joint
interference, flat-face inverse mapping, contour topology and STL roundoff cleanup.
All nine final exported parts passed mesh checks. No physical print or lighting
test has been performed.

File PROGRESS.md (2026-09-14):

# Progress log

Every progress summary should be added in a different section titled with the date and the
incremental number of the progress (+1 the previous).

---

## 1 — 2026-09-13

### Scope

Investigated why an uploaded SVG kept showing the default sunburst, then added the wall
standoff. Features 1–4 of the five requested (cover artwork from a second SVG, hollow
pillar, manual XY supports with a coordinate grid, XY shadow placement) already existed by
the time the merge happened — see *Collision* below.

Everything stated here was rendered and measured with OpenSCAD 2021.01, not reasoned about
on paper.

### Why an uploaded SVG showed the default sunburst

Not a bug — a gate, in `normalized_artwork()`:

```
if(Embedded_artwork) embedded_artwork();
else if(Use_svg)     import(file=Svg_file, ...);
else                 demo_artwork();          // the sunburst
```

`Use_svg` defaulted to `false`. MakerWorld's upload convention swaps the *contents* of
`default.svg`; the variable's name and value never change, so nothing in the script can
detect that an upload happened. Uploading without ticking `Use_svg` did nothing.

Two follow-on traps found at the same time:

- A file produced by `prepare_svg.py` sets `Embedded_artwork = true`, which short-circuits
  before `Use_svg`. Its upload control stays visible but is inert by design.
- Enabling direct SVG mode switches the envelope factor `k` from 0.5 to `sqrt(2)/2`. At the
  stock 300 mm / 5% detail that gives a **0.384 mm** cut estimate against the 0.4 mm limit,
  so it reports GENERATION NOT POSSIBLE. 280 mm clears it (0.411 mm).

The `Artwork_source` dropdown that replaced the boolean removes the footgun.

### Collision with a parallel session

Mid-session, `modular_shadow_lamp.scad` on disk grew from 17 KB to 27 KB and new files
appeared (`run_local.py`, `Open two SVGs locally.cmd`). Another Claude session had
implemented the cover artwork, manual XY supports, the coordinate grid and the XY shadow
placement.

Work already built here against the stale baseline was **discarded rather than committed**.
Only the wall standoff — the one feature that version lacked — was ported onto it. Nothing
the other session wrote was overwritten.

*If two sessions run on this folder again, give each one a file it owns.*

### Added: the wall standoff

`Wall_standoff` is the clear gap held between the room wall and the module's back. **0 is
flush and reproduces the previous geometry byte for byte.** The gap is a closed compartment
with the keyholes and cable route on its own back plate (`Standoff_back`).

`Standoff_mode` chooses how it is built:

- **Separate ring** — `Output = "Standoff"` prints it as its own part, driving the standard
  keyed tongue into the body's existing rear socket. Change the standoff without reprinting
  the optical body. Requires `Wall_standoff >= Standoff_back`.
- **Extended body** — the body grows backwards as one piece, no extra joint. Its rear socket
  is suppressed, because a blind socket there would seal a void inside the part.

Optically a standoff is identical to mounting the module further into the room: every
mechanical plane translates with it, so the source rises by exactly the standoff and radial
resolution improves in proportion. It is not free — `rho_dead = R*h/(h-A)` has `h` and `A`
rising together, so the hidden centre widens at a similar rate.

| Standoff | Source height | Cut estimate | Hidden radius |
|---:|---:|---:|---:|
| 0 mm | 24 mm | 0.768 mm | 64.9 mm |
| 20 mm | 44 mm | 1.408 mm | 118.9 mm |
| 50 mm | 74 mm | 2.368 mm | 200.0 mm |

So it pays off only if the image grows with the gap. On the default 100 × 30 mm module,
50 mm of standoff **rejects** a 300 mm image — the 200 mm dead radius swallows it — while
projecting **600 mm** comfortably at a 1.184 mm cut estimate, a length the flush module
cannot reach at all.

`prepare_svg.py` gained `--wall-standoff` and `--standoff-mode`. The ring is mesh-checked
alongside the body and cover and written to `<name>_standoff.stl`.

```powershell
python prepare_svg.py artwork.svg --wall-standoff 25 --length 500 --output output/my_lamp.scad
```

### The hollow pillar already existed

No change needed. `Pillar_wire_bore` (3 mm) has always run the full pillar height into the
rear cable route under the opaque back. `tests/check_feature_meshes.py` already proves the
axial path is clear by ray-casting through the exported mesh at x=y=0.

### Evidence

- **22 unit tests pass** — 13 existing, 9 new in `tests/test_standoff.py`.
- **No regression**: at `Wall_standoff = 0`, Body, Cover and Cover base render identical
  triangle counts, volumes and bounds to the pre-merge file.
- **Joint fit**: `tests/check_joint_fit.py` now also intersects the standoff ring with the
  seated body. Empty at 0.01 mm separation, like the cover and stacking pairs.
- **Mesh quality**: the ring, the body-with-ring and the extended body are each one closed
  two-manifold surface component, each sitting on z=0 as exported.
- **The compartment is vented, not sealed** — it breathes through the pillar bore, which is
  why the assembly stays a single surface component. Tested directly.
- **Full helper run** with a standoff produced body, cover and ring, all passing preflight.

### Files touched

`modular_shadow_lamp.scad`, `prepare_svg.py`, `README.md`, `OPTICS.md`,
`package_project.py`, `tests/check_joint_fit.py`, and new `tests/test_standoff.py`.

### Open / untested

- Nothing has been printed. The ring's tongue clears in CGAL; that is not a fit felt in PLA.
- The compartment is a void with a cable route. Driver placement, insulation, clearances,
  heat and any mains-side design are untouched and untested.
- The Diagnostics suggestion search varies module height, never the standoff. When it
  refuses a length it will not propose a standoff as the fix — try one by hand.
- `Standoff_back` is not checked against the pull-out load of the keyhole screws.
- A `.git` folder appeared in the project during the session. These files are uncommitted
  working-tree changes; check `git status` before anything checks out over them.

## 2 — 2026-09-13

### Reference-driven housing and stencil improvements

Used the supplied `itachi_example.svg` and `monza_example.svg`. Confirmed that the
standoff is already included in the source, cone and clipping calculations. Fixed
the lower-module stack display to include it too. The new `compare_designs.py`
samples 4,320 combinations per reference across housing size/shape, optical height,
standoff, image length and XY placement; it measures visible filled-SVG area and
counts body plus standoff as total depth. Reports retain the explicit assumptions
and sampled bounds rather than claiming a global optimum.

Added `Housing_shape = Rectangle`, with independent width and depth. The body,
cover, joints, electronics standoff and actual projected obstruction all follow
the footprint. Rectangular compression uses a conservative bound that includes
the shear of the flat-face inverse projection.

Added optional `--minimum-web` preparation on the developed inner shell, using
NumPy/Pillow. This simplifies fine opaque slivers and retains original vector
light elsewhere. `--automatic-bridges-only` starts without blanket spokes; mesh
preflight removes explicitly reported tiny detached specks and adds short 0.9 mm
ribs beneath larger islands. Finite rib shadows are included in Projection.
Relevant edits invalidate prepared surface data and block stale body exports.

The user confirmed a 0.4 mm nozzle. The 0.2 mm LED emitting-area assumption is
still unconfirmed. The 0.4 mm small-aperture screen is diagnostic, not an exact
stroke-width measurement or a printability certificate.

### Prepared results

| Model | Housing | Optical height + standoff | Artwork length | Original light area retained |
|---|---|---|---|---|
| `itachi_final` | Ø80 mm | 44 + 10 mm | 800 mm | 88.39% |
| `monza_final` | Ø80 mm | 36 + 10 mm | 600 mm | 97.25% |
| `monza_rectangle_final` | 80 × 80 mm | 36 + 10 mm | 600 mm | 94.69% |

Each has a standalone SCAD, body/cover/standoff STL and JSON report in `output/`.
Itachi uses eight short ribs and removes four tiny specks. Monza needs no added
ribs in either final housing. A taller optical section with a smaller standoff
preserved much more Itachi artwork than the earlier 30 + 30 mm trial, despite
being shallower in total.

### Evidence and limits

- 29 distinct automated tests passed: the 28-test suite plus a new rectangular
  cover/body/stack/standoff interference check.
- All nine final parts have one surface component and closed two-manifold edges.
- Binary STL export exposed four collapsed triangles at the retaining holes in
  the cylindrical reference bodies. Welding export coincidences at 0.000001 mm
  and removing collapsed triangles resolves the numerical failure; real islands
  are handled separately and never hidden by that cleanup.
- `inspect_projection.py` independently projects the opaque STL at the correct
  wall offset. Agreement with the analytic preview is 99.02% for Itachi at
  5,000 pixels and 97.84% / 97.95% for cylindrical / rectangular Monza at 10,000
  pixels. Narrow outlines have measurable raster-boundary error.
- Cleanup changes the artwork. Itachi gains light equivalent to 8.13% of the
  visible reference area and loses 1.68%; Monza gains 3.91% / 2.33%. Side-by-side
  images expose these changes.
- These candidate sizes use the original 5% declared-detail assumption, not a
  measurement of the finest SVG detail. The stricter 2% study gives much less
  compact results. Monza still has significant small-aperture flags.
- No slicer, physical print, real LED, driver fit, thermal or mechanical-load
  test was performed. The 10 mm compartment is a candidate, not a measured fit.

See `DESIGN_REVIEW.md` for the findings and remaining trade-offs, `README.md` for
commands, and `OPTICS.md` for the rectangular projection and surface processing.

---

## 3 — 2026-09-13

### Added: light limit for dark silhouette

`Light_limit` bounds the lit field in `Artwork_mode = "Dark silhouette"`. Off, the shadow sits
in a disc reaching the full beam radius. On, light is a band of `Light_limit_thickness` mm
hugging the shadow, and beyond it the wall is dark again. `Light_limit_shape` picks the
bounding region:

- **Same as shadow** — `offset(r=T)` of the artwork. Rounded corners: a mitred outset spikes
  at acute corners into slivers too fine to print.
- **Circle** — the artwork's bounding circle plus T. Larger than the unlimited disc whenever
  T exceeds `Dark_field_border`, so it sizes the disc explicitly rather than shrinking it.
- **Rectangle** — the artwork's **true** bounding box plus T, turning with `Artwork_rotation`.
  `prepare_svg.py` now measures the proportions and writes `Embedded_extent`; a directly
  imported SVG has no measured extent and falls back to a square.

Helper flags: `--light-limit`, `--light-limit-shape`, `--light-limit-thickness`.

### Design decisions taken

| Question | Chosen |
|---|---|
| Corner treatment for "Same as shadow" | Rounded (`offset(r=)`) |
| Rectangle sizing | True artwork bounding box, measured by the helper |
| Band too thin to print | Warn, report the minimum, build anyway |

### The band width is a known feature, not a declared one

Unlike `Smallest_detail_percent`, the band width is a real dimension the generator knows, so
it computes the slot exactly and warns rather than guessing. Flush, 300 mm image:

| Band | Slot in the shell |
|---:|---|
| 5 mm | 0.240 mm — warned |
| 10 mm | 0.450 mm |
| 25 mm | 0.940 mm |
| 50 mm | 1.440 mm |

Thinnest band clearing a 0.4 mm slot: 8.8 mm flush at 300 mm, 4.5 mm with a 20 mm standoff,
10.9 mm at 50 mm standoff / 600 mm. `rho_max` contains T, so the floor has no closed form —
the generator settles it by repeated substitution, and a test confirms the number it suggests
really does clear the limit.

### Follow-up: bounding one side only

The first cut bounded both sides at once, which is wrong for a closed outline. On
`monza_example.svg` the track is a thin closed ribbon, so `offset(r=T)` grew the outside
correctly and simultaneously ate the infield, leaving a band on each side of the track
instead of a lit interior.

`Light_limit_outside` and `Light_limit_inside` are now separate switches. All four
combinations work; `outside on / inside off` is the circuit-map case.

The fix needs the artwork's **silhouette** — its outermost contours with every hole filled —
because `offset()` moves every boundary at once and no morphological trick recovers a filled
hole faithfully (a closing fills only up to its own radius and rounds everything else). The
helper now derives it from contour topology: flatten through OpenSCAD, count how many
contours of the same path contain each contour, keep those at even-odd depth zero, and write
them into the file as a separate `embedded_artwork_outline()` module. On Monza that selects
exactly one contour out of three — the outer boundary at 48,215 units against the enclosed
interior at −41,971 and a degenerate 7-point sliver.

The field then splits at the silhouette: outside it, bounded by the chosen shape or not;
inside it, bounded by the T band or not. Both switches off reproduce the plain dark
silhouette to within 0.2%, which is asserted rather than assumed.

This is only available on prepared artwork. A directly uploaded SVG has no silhouette —
contour nesting is a property of the path data, not of what `import()` returns — so the
generator applies one setting to both sides and echoes a note explaining why. Helper flags:
`--light-limit-outside on|off`, `--light-limit-inside on|off`.

Marker collision worth remembering: the new block was first called
`// BEGIN EMBEDDED ARTWORK OUTLINE`, which the existing non-greedy
`// BEGIN EMBEDDED ARTWORK.*?// END EMBEDDED ARTWORK` substitution matches as a prefix. Renamed
to `// BEGIN ARTWORK SILHOUETTE`. Any future block must not be a prefix of another.

### The failure mode this created

Reported as "inside off does nothing". It did nothing, correctly: the artwork was a direct
SVG import with no silhouette, so the fallback applied the outside setting to both sides. The
only sign was a console echo, and the Projection view looked exactly like the feature being
broken.

Every prepared file in `output/` predates the silhouette, so no file on disk could have
worked; the setting has to be used on artwork prepared after this change.

Two fixes so it cannot happen silently again:

- The Diagnostics **overlay** now carries `Limited outside: yes, inside: no` and appends
  `<- IGNORED, artwork has no silhouette: rerun prepare_svg.py` when the fallback is active.
  On screen, where the person actually is, not only in the console.
- `run_local.py` now passes `--dark-silhouette`, `--light-limit`, `--light-limit-shape`,
  `--light-limit-thickness`, `--light-limit-outside` and `--light-limit-inside` through to the
  helper, so the quick preview can drive the feature instead of needing a hand edit afterwards.

A setting that is silently ignored looks identical to a broken feature. Anything that can be
overridden by a missing prerequisite belongs in the overlay, not in an echo.

Neither fix was enough, because the answer was still "use the helper" and the helper cannot
run on MakerWorld at all. `Interior_span` now makes the direct-import path work: the widest
enclosed area to treat as interior, in mm, with the interior found by a mitred morphological
closing instead of a measured silhouette.

Measured against the exact silhouette on Monza at L=300 (true fill 19,304 mm^2), the closing
lands within **0.6% at S=60 mm and 1.5% at S=200 mm**, under-fills sharply below half the
enclosed width (60% error at S=40), and drifts toward the convex hull far above it (13% at
S=450, hull 28,628). The usable window spans roughly half the enclosed width to the artwork's
own length. Rounded joins were rejected: `offset(r=)` pulls the outer boundary inwards during
erosion; mitred joins restore it exactly.

A measured silhouette still wins where one exists, and Diagnostics states which method
produced the interior so the approximation is never passed off as exact.

### Follow-up: a wrong `Svg long axis` was lying to the optics

Reported as "the shadow doesn't show complete" when switching the axis from Y to X.

`resize([1,0],auto=true)` normalises the **declared** axis. Monza is three times taller than
wide, so declaring X scales it up until Y reaches 257 mm at `Shadow_length = 300`, a corner
reach of 298 mm -- while `k = sqrt(2)/2` and everything built on it still assumed the artwork
fits a 300 mm square, a declared radius of 212 mm. A **38% understatement of the envelope**:
source height, cut, blur and feasibility were all computed against an artwork smaller than the
one actually being cut, and the preview spilled off the wall board.

Fixed two ways:

- A direct import is now intersected with a `Shadow_length` square. A correct declaration
  already fits, so the clamp is a no-op; a wrong one crops with a visible straight edge and
  the optics stay honest. Measured: axis X now reaches 209.9 mm against the declared 212.1,
  where it previously reached 298.
- `view_extent` now covers `1.05*r_far`, so the dark board reaches past the footprint instead
  of letting the projection spill onto the background and read as a clipped shadow.

Prepared artwork carries its measured radius and is not clamped.

### Customizer descriptions: OpenSCAD shows only the LAST comment line

Every multi-line description written for these parameters was being truncated to its final
line, so `Interior_span` displayed "for a single closed outline. Prepared artwork measures
this exactly and ignores it." and dropped the half saying what to set and that 0 means
ignored. That is a large part of why this feature looked broken twice.

All parameter descriptions are now single self-contained lines, with longer rationale on the
lines **above** -- ignored by the customizer, still read in the file. Anything a user must
know in order to set a value correctly belongs on the last line.

### Follow-up: `Interior_span` had to become automatic

Reported a third time as "even with internal light limit off you still get light limit
inside". Measured on Monza at `Shadow_length = 1000`, lit area with the inside limit ON is
131,459 mm^2:

| Interior_span | Silhouette found | Lit area | Effect |
|---:|---:|---:|---|
| 0 (was: ignored) | 27,737 = the artwork | 131,459 | nothing |
| 100 | 26,565 | 131,459 | nothing, silently |
| 300 | 215,259 | 255,217 | works |
| 500 | 215,802 | 255,217 | works |

The feature was correct; the default was useless and a too-small value did nothing while the
console still claimed the interior had been closed. Below the threshold the closing returns
roughly the artwork back, so the union changes nothing.

`Interior_span = 0` now means **automatic = `Shadow_length`**. An enclosed area cannot be
wider than the artwork enclosing it, so that value can never under-fill -- it is the only
setting with that property. Verified: automatic and a hand-picked 500 mm give an identical
255,217 mm^2 at L=1000, and at L=300 both give 38,641 against 36,660 with the limit on.

Over-filling was the worry, and it was measured rather than assumed. On `two_rings`, which is
two separate shapes, spans of 0.25L, 0.5L and 1.0L all leave **two pieces** -- no fusion --
costing 16% extra outline area at 1.0L. On Monza at 1000, 0.25L finds only a partial interior
in two pieces, and 0.5L and above find the whole thing in one. Under-filling silently is far
worse than over-filling visibly, so the guaranteed value wins.

The fallback that made the two sides share one setting is gone: the interior is now always
computable, so `Light_limit_inside` is always honoured.

### Two consequences, both measured

- **The band strands what it encircles.** With supports off, a limited field leaves exactly the
  same number of detached components as the unlimited disc already did. Structural, not a
  regression, and no thickness avoids it — but bridges must stay on and their lines cross
  the band.
- **Widening the band fuses nearby halos.** On `two_rings` at 160 mm, 3/8/20 mm bands keep four
  separate lit regions; a 40 mm band drops to three. Nothing warns about this.

### Evidence

- **21 new tests** in `tests/test_light_limit.py`; **50 in the suite, all passing.**
- **Side independence**: freeing the inside and freeing the outside separately add up to
  freeing both, measured on real renders rather than argued.
- **Silhouette normalisation**: the silhouette and the artwork are asserted to share the same
  centre and scale, since a mismatch would slide the fill off the artwork.
- **No regression**: with the limit off, both Light shapes and Dark silhouette bodies render
  identical triangle counts and volumes to the pre-change file.
- **Identity check**: the band's area equals the grown artwork minus the artwork, rendered and
  measured as three separate probes rather than asserted.
- **Envelope check**: a rectangle's reported reach is `hypot(175,175)` where a circle's is 175,
  confirming the optics use the corner.
- **Full helper run** with `--dark-silhouette --light-limit` passed mesh preflight, and the
  measured `Embedded_extent` for `two_rings` came out `[0.333, 1.0]` as expected.
- Joint fit still passes both pairs.

### Also investigated: Inkscape clips are ignored

`clip-path`, `mask`, `display:none` and `visibility:hidden` are all discarded by OpenSCAD's
SVG importer — a clipped 180 mm bar imports at exactly the same 47.62 mm width and 504 volume
as the unclipped one. Content outside the page imports too. Cropping must be baked into the
geometry (`Path > Union`, then `Path > Intersection`), and hidden layers deleted rather than
hidden. **Not yet handled in code**: `prepare_svg.py` flattens through OpenSCAD, so it inherits
the same blindness and will pass preflight on artwork that is not what you see in Inkscape. A
`--crop` option plus a refusal when `clip-path`/`mask`/`display:none` is present was offered
and not yet built.

### Open / untested

- Nothing printed. No band has been cut in plastic, so the slot-width floor is geometry, not
  a measured print result.
- The halo-fusion behaviour is silent; Diagnostics does not detect or report it.
- The Diagnostics suggestion search varies module height only — it will not propose widening
  the band or adding a standoff when a band is too fine.

---

## 4 — 2026-09-14

### Quality limits warn instead of refusing

"Too much impossible in generation." Fair: one verdict was covering two unrelated things.

`feasible()` mixed hard geometry with print-quality thresholds, so a cut estimate 0.03 mm under
the minimum refused exactly as hard as a pillar that does not fit its own cavity. Split into:

- `buildable(H,L)` — mechanical clearances, source between the floor and the ceiling, and an
  image that still reaches outside the occluded centre. Refuses, always, in any mode.
- `quality_ok(H,L)` — cut width and blur. Warns; the part builds.

`feasible = buildable && quality_ok` still drives the suggestion search, so the suggested
dimensions remain fully feasible rather than merely buildable.

`Quality_limits = "Warn"` is the default; `"Refuse"` restores the old gate.

Classified against real renders before the tests were written:

| Request | Verdict |
|---|---|
| direct SVG at 1000 mm | BELOW QUALITY LIMITS — builds |
| `Emitter_diameter = 5` | BELOW QUALITY LIMITS — builds |
| `Emitter_axial_depth = 1` | BELOW QUALITY LIMITS — builds |
| `Shadow_length = 600` flush | BELOW QUALITY LIMITS — builds |
| `Manual_LED_height = 0` | GENERATION NOT POSSIBLE — source below the pillar |
| 50 mm standoff, 300 mm image | GENERATION NOT POSSIBLE — dead disc swallows it |

Monza at 1000 mm now exports a closed single-component body of 15,112 triangles where it
previously refused outright, and the helper completes with
`CONNECTED BODY; CLOSED TWO-MANIFOLD EDGES; BELOW QUALITY LIMITS`.

Diagnostics shows amber for "builds but coarse" and red only for geometry that cannot exist,
and the warning names the failing number rather than saying the request is impossible.

### Evidence

- **68 tests, all passing**; 5 new in `tests/test_standoff.py::QualityGateTests`.
- Three existing tests asserted the old combined refusal and were updated to assert the
  correct half of the split — including one that now checks a source below the pillar still
  refuses **while Quality_limits is set to Warn**, which is the property that matters.
- The default demo body is byte-identical: 46,590.745 mm^3.

### Open / untested

- The suggestion search still varies module height only. It will not propose a standoff, a
  larger diameter or a wider band when one of those is the real fix.
- Nothing here changes what actually prints. A 0.114 mm slot still will not open on a 0.4 mm
  nozzle; the generator now shows it to you instead of deciding for you.

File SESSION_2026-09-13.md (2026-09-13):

# Session record — 12/13 September 2026

Two things happened in this session: an investigation into why uploaded SVGs were ignored,
and the addition of the wall standoff. Everything below was rendered and measured with
OpenSCAD 2021.01, not reasoned about on paper.

## 1. Why an uploaded SVG showed the default sunburst

Not a bug — a gate, in `normalized_artwork()`:

```
if(Embedded_artwork) embedded_artwork();
else if(Use_svg)     import(file=Svg_file, ...);
else                 demo_artwork();          // the sunburst
```

`Use_svg` defaulted to `false`. MakerWorld's upload convention swaps the *contents* of
`default.svg`; the variable's name and value never change, so nothing in the script can
detect that an upload happened. Uploading without ticking `Use_svg` therefore did nothing.

Two follow-on traps found at the same time:

- A file produced by `prepare_svg.py` sets `Embedded_artwork = true`, which short-circuits
  before `Use_svg`. Its upload control stays visible but is inert by design.
- Enabling direct SVG mode switches the envelope factor `k` from 0.5 to `sqrt(2)/2`. At the
  stock 300 mm / 5% detail this gives a **0.384 mm** cut estimate against the 0.4 mm limit,
  so it reports GENERATION NOT POSSIBLE. 280 mm clears it (0.411 mm).

A parallel session has since replaced the boolean with an `Artwork_source` dropdown, which
removes the footgun.

## 2. A parallel session had edited the same folder

Mid-session, `modular_shadow_lamp.scad` on disk grew from 17 KB to 27 KB and new files
appeared (`run_local.py`, `Open two SVGs locally.cmd`). Another session had implemented the
cover artwork, manual XY supports, the coordinate grid and the XY shadow placement.

Work already done here against the stale baseline was **discarded rather than committed**.
Only the wall standoff — the one feature that version lacked — was ported onto it. Nothing
the other session wrote was overwritten.

If two Claude sessions run on this folder again, give each one a file it owns.

## 3. What was added: the wall standoff

`Wall_standoff` is the clear gap held between the room wall and the module's back. **0 is
flush and reproduces the previous geometry byte for byte.** The gap is a closed compartment
with the keyholes and cable route on its own back plate (`Standoff_back`).

`Standoff_mode` chooses how it is built:

- **Separate ring** — `Output = "Standoff"` prints it as its own part, driving the standard
  keyed tongue into the body's existing rear socket. Change the standoff without reprinting
  the optical body. Requires `Wall_standoff >= Standoff_back`.
- **Extended body** — the body grows backwards as one piece, no extra joint. Its rear socket
  is suppressed, because a blind socket there would seal a void inside the part.

### The trade-off, measured

Optically a standoff is identical to mounting the module further into the room: every
mechanical plane translates with it, so the source rises by exactly the standoff and radial
resolution improves in proportion. It is not free — `rho_dead = R*h/(h-A)` has `h` and `A`
rising together, so the hidden centre widens at a similar rate.

| Standoff | Source height | Cut estimate | Hidden radius |
|---:|---:|---:|---:|
| 0 mm | 24 mm | 0.768 mm | 64.9 mm |
| 20 mm | 44 mm | 1.408 mm | 118.9 mm |
| 50 mm | 74 mm | 2.368 mm | 200.0 mm |

So it pays off only if the image grows with the gap. On the default 100 x 30 mm module,
50 mm of standoff **rejects** a 300 mm image — the 200 mm dead radius swallows it — while
projecting **600 mm** comfortably at a 1.184 mm cut estimate, a length the flush module
cannot reach at all.

### Helper

```powershell
python prepare_svg.py artwork.svg --wall-standoff 25 --length 500 --output output/my_lamp.scad
```

`--wall-standoff` and `--standoff-mode` are new. The ring is mesh-checked alongside the body
and cover and written to `<name>_standoff.stl`.

## 4. The hollow pillar was already there

No change needed. `Pillar_wire_bore` (3 mm) has always run the full pillar height into the
rear cable route under the opaque back. `tests/check_feature_meshes.py` already proves the
axial path is clear by ray-casting through the exported mesh at x=y=0.

## 5. Evidence

- **22 unit tests pass** — 13 existing, 9 new in `tests/test_standoff.py`.
- **No regression**: with `Wall_standoff = 0`, Body, Cover and Cover base render identical
  triangle counts, volumes and bounds to the pre-merge file.
- **Joint fit**: `tests/check_joint_fit.py` now also intersects the standoff ring with the
  seated body. Empty at 0.01 mm separation, like the cover and stacking pairs.
- **Mesh quality**: the ring, the body-with-ring and the extended body are each one closed
  two-manifold surface component, each sitting on z=0 as exported.
- **The compartment is vented, not sealed** — it breathes through the pillar bore, which is
  why the assembly stays a single surface component. Tested directly.
- **Full helper run** with a standoff produced body, cover and ring, all passing preflight.

## 6. Not done, not tested

- Nothing has been printed. The ring's tongue clears in CGAL; that is not a fit felt in PLA.
- The compartment is a void with a cable route. Driver placement, insulation, clearances,
  heat and any mains-side design are untouched and untested.
- The suggestion search in Diagnostics varies module height, never the standoff. When it
  refuses, it will not propose a standoff as the fix — try one by hand.
- `Standoff_back` is not checked against the pull-out load of the keyhole screws.
- A `.git` folder appeared in the project during the session. These files are uncommitted
  working-tree changes; check `git status` before anything checks out over them.

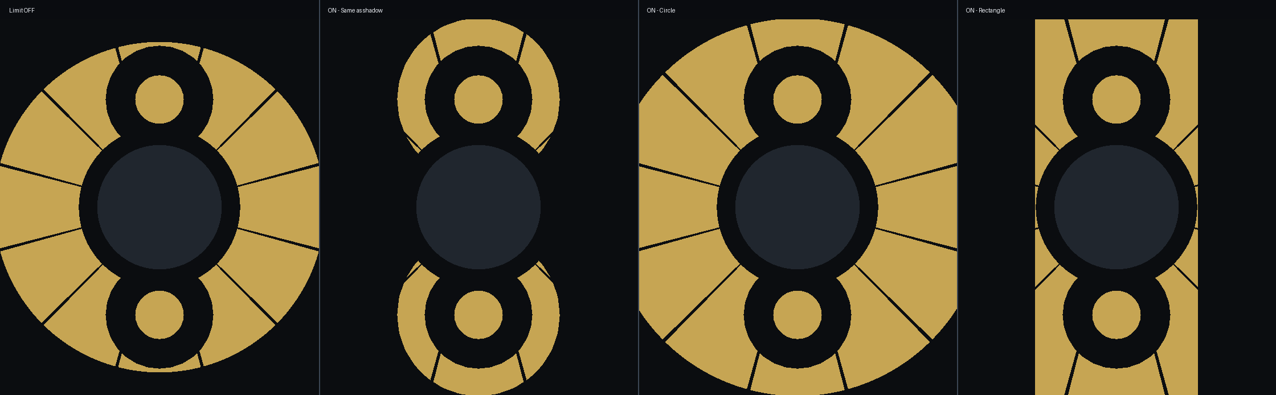
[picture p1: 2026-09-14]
Claude outputs/light_limit_real.png

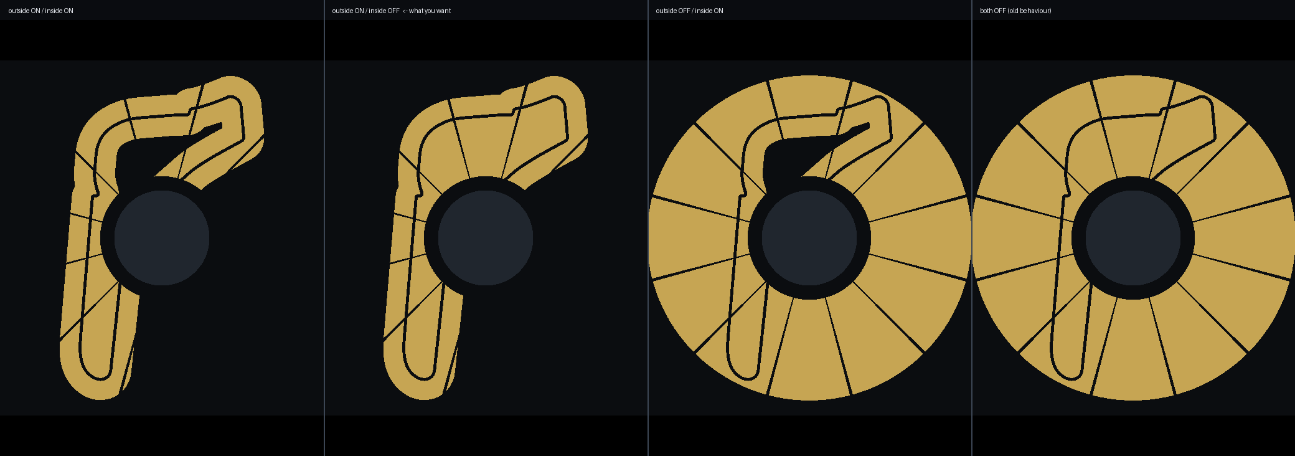
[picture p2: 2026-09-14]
Claude outputs/light_limit_sides.png

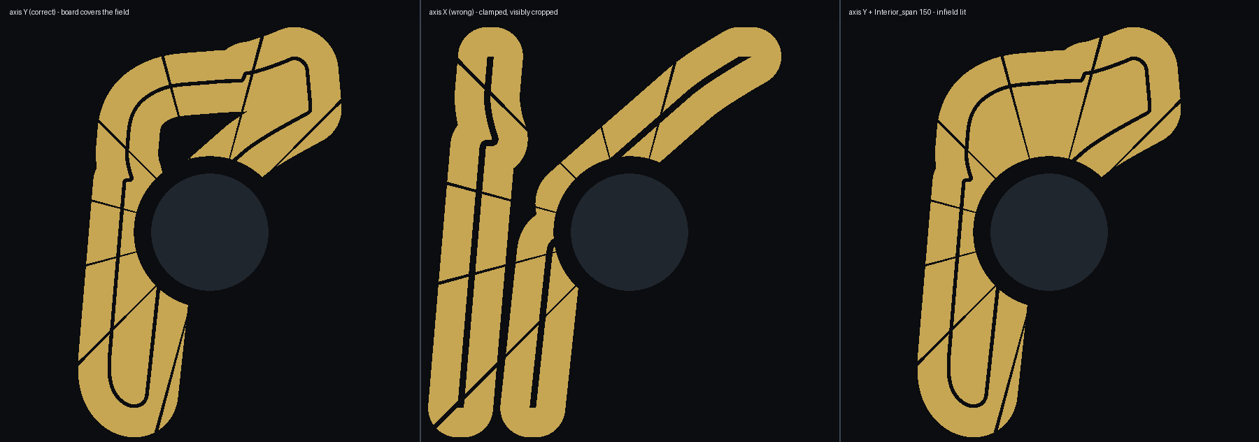
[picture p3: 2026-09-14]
Claude outputs/axis_clamp.png

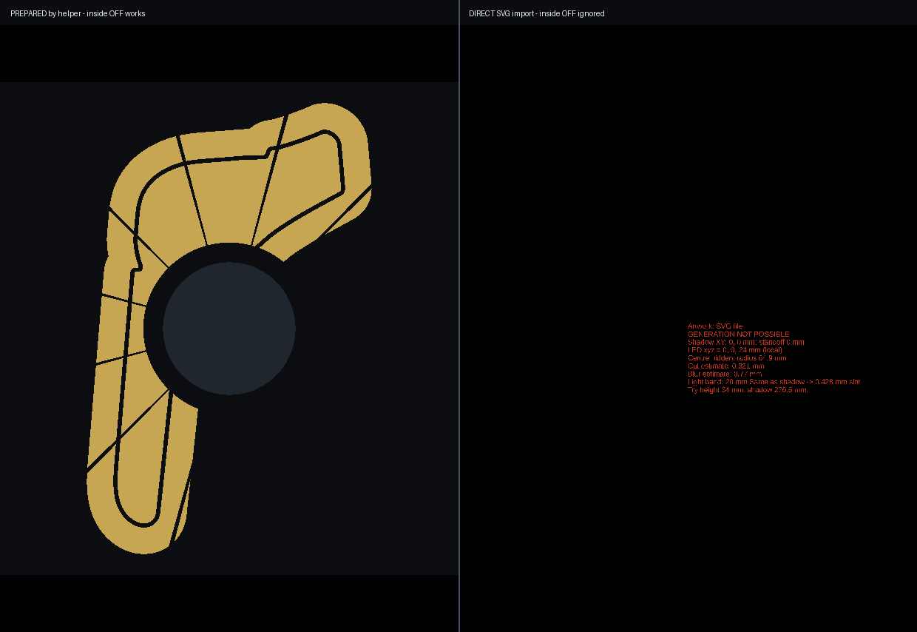
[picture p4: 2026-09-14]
Claude outputs/inside_off_diagnosis.png

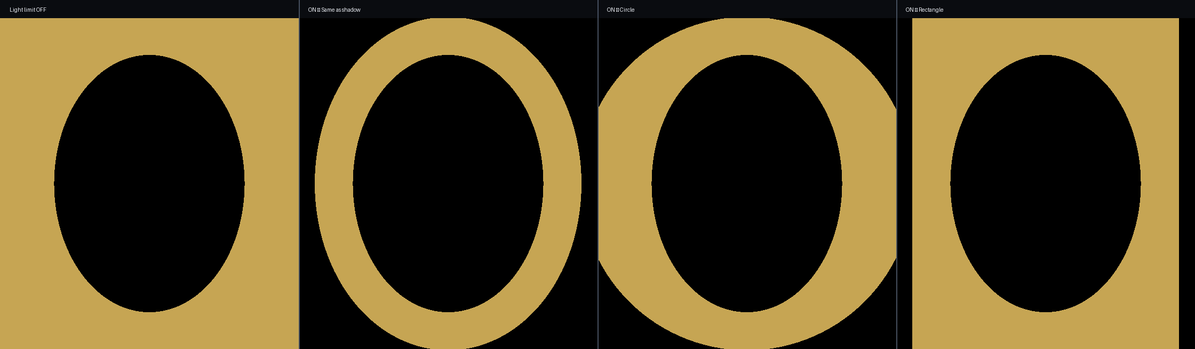
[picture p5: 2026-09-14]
Claude outputs/light_limit_prototype.png

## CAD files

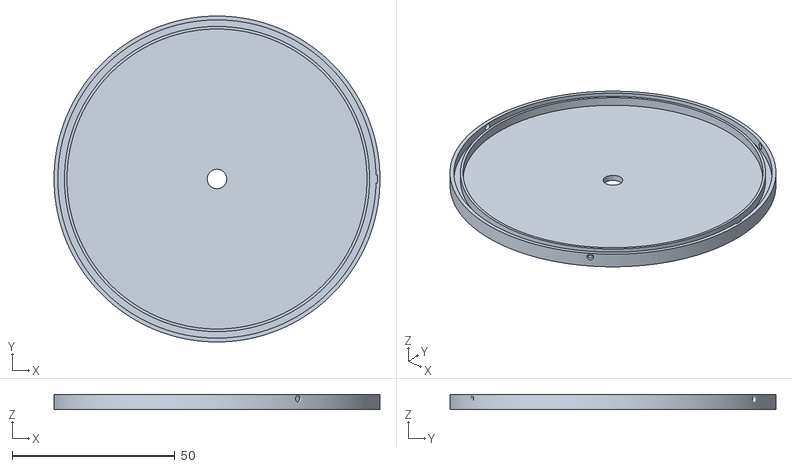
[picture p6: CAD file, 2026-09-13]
output/features_demo_preflight/cover.stl
100.0 x 100.0 x 4.50

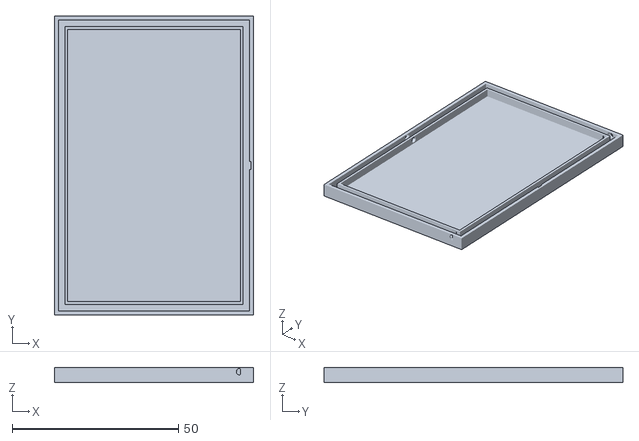
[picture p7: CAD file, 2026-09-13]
output/housing_tests/rectangle_cover.stl
60.0 x 90.0 x 4.50

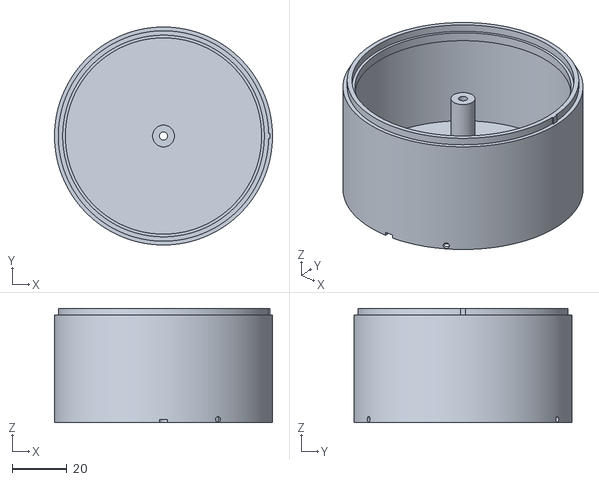
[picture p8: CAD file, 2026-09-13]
output/itachi_balanced_preflight/body_0.stl
80.0 x 80.0 x 42.0

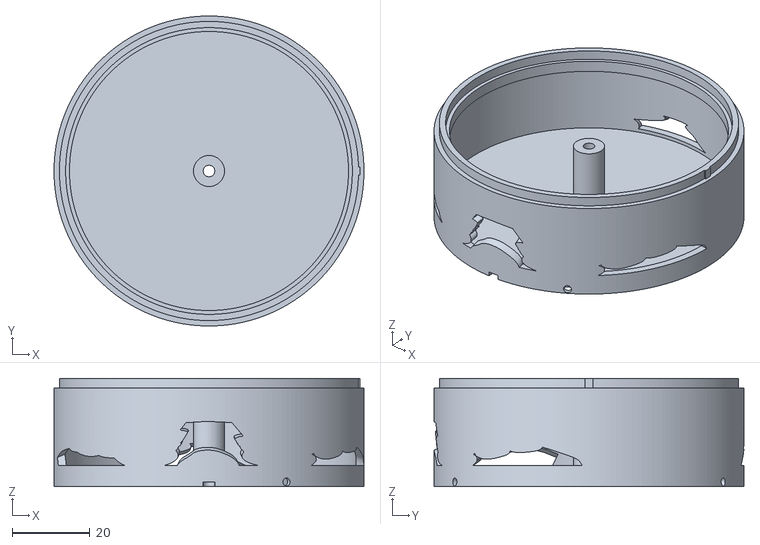
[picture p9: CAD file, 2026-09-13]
output/itachi_compact_preflight/body_0.stl
80.0 x 80.0 x 28.0

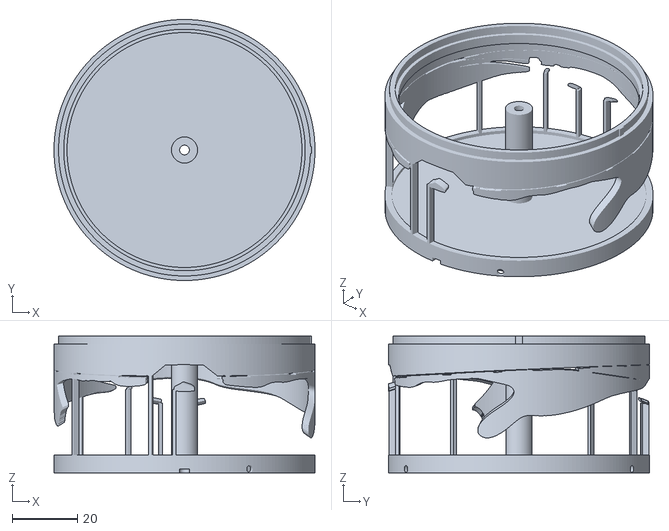
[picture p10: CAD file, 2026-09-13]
output/itachi_final_preflight/body_1.stl
80.0 x 80.0 x 42.0

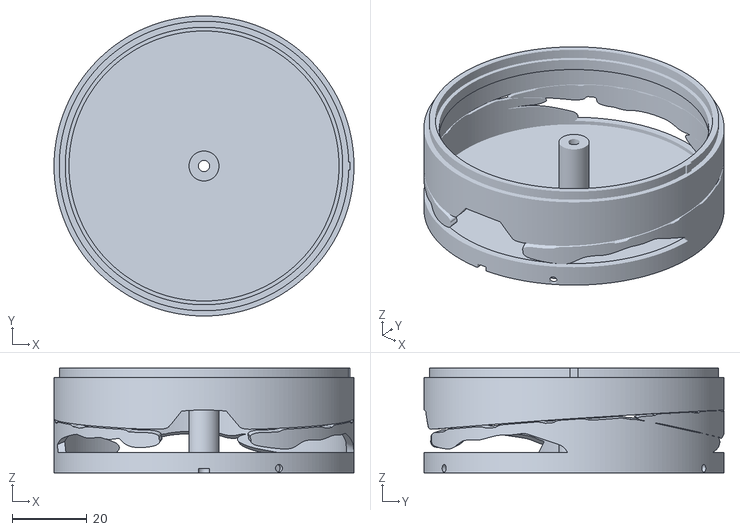
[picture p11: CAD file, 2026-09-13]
output/itachi_refined_preflight/body_0.stl
80.0 x 80.0 x 28.0

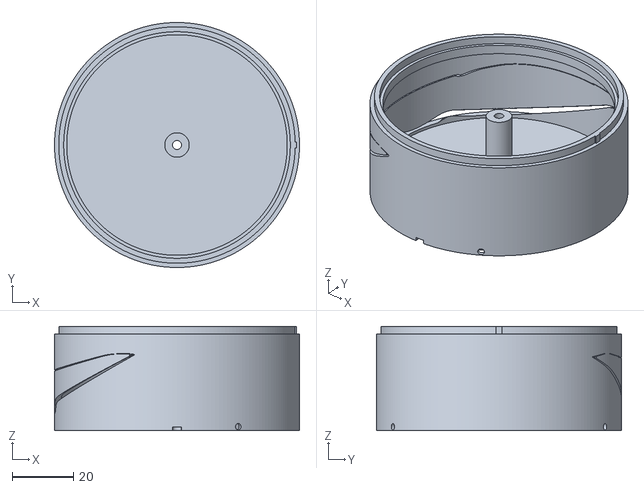
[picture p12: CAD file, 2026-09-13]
output/monza_balanced_preflight/body_0.stl
80.0 x 80.0 x 34.0

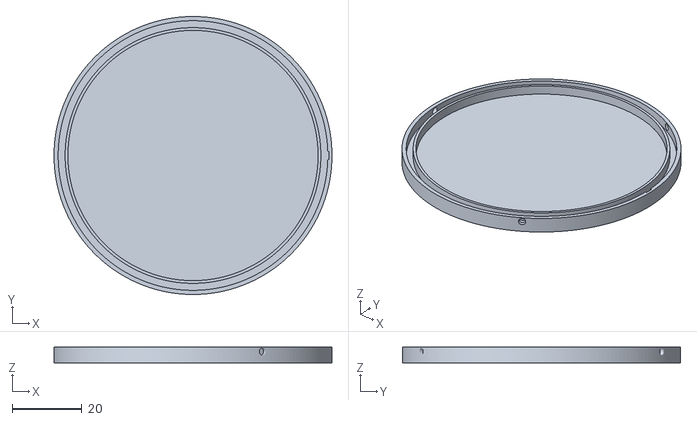
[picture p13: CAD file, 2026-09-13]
output/monza_compact_preflight/cover.stl
80.0 x 80.0 x 4.50

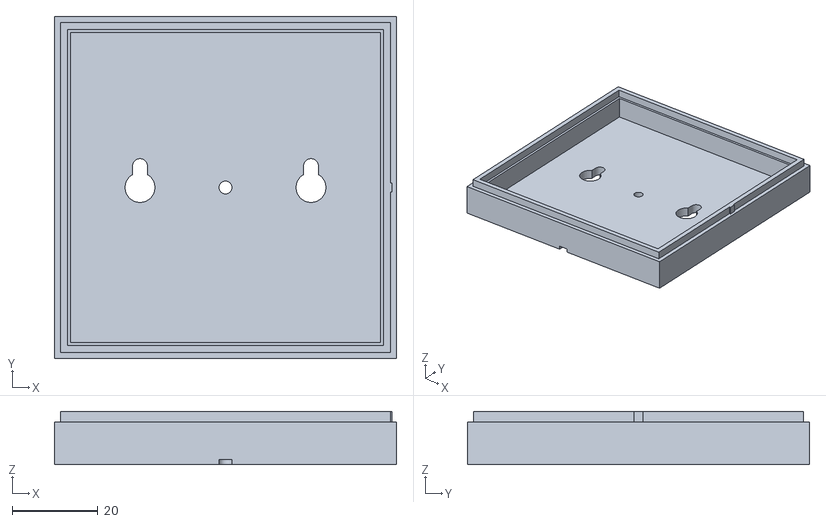
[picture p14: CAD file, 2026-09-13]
output/monza_rectangle_final_preflight/standoff.stl
80.0 x 80.0 x 12.5

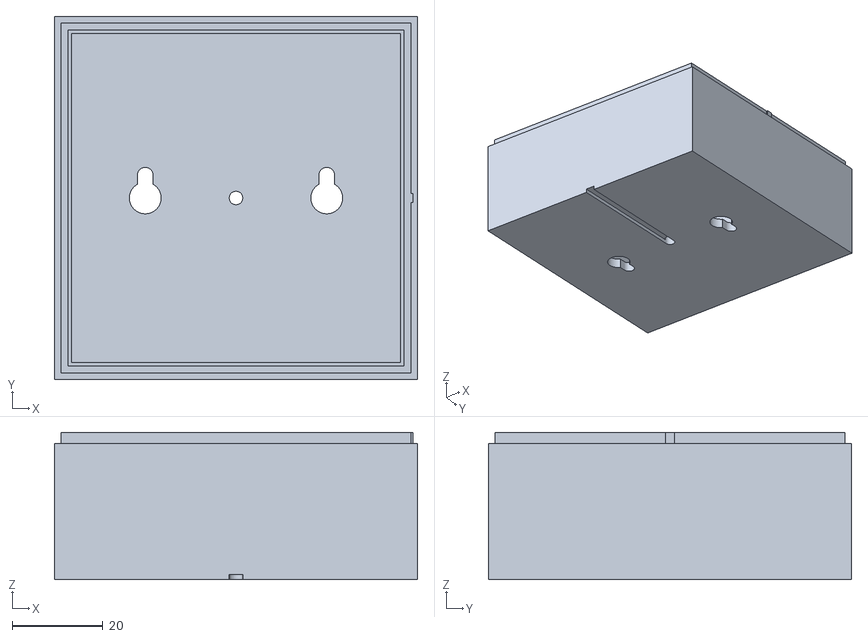
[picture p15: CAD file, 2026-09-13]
output/monza_rectangle_preflight/standoff.stl
80.0 x 80.0 x 32.5

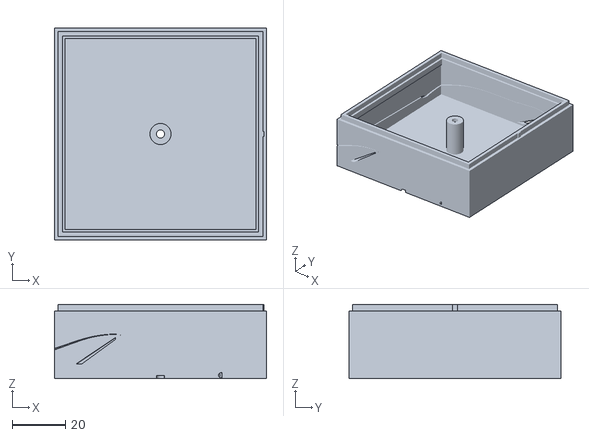
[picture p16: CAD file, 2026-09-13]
output/monza_surface_rectangle.stl
80.0 x 80.0 x 28.0

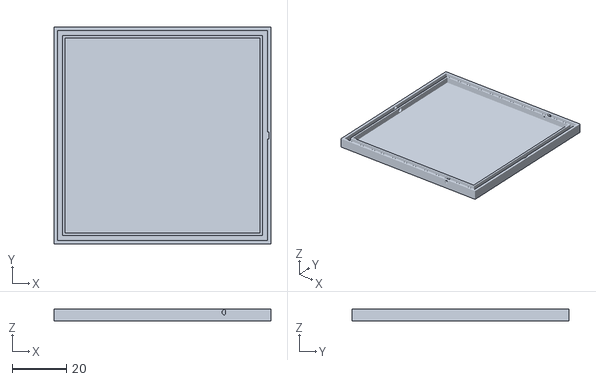
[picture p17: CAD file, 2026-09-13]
output/monza_surface_rectangle_preflight/cover.stl
80.0 x 80.0 x 4.50

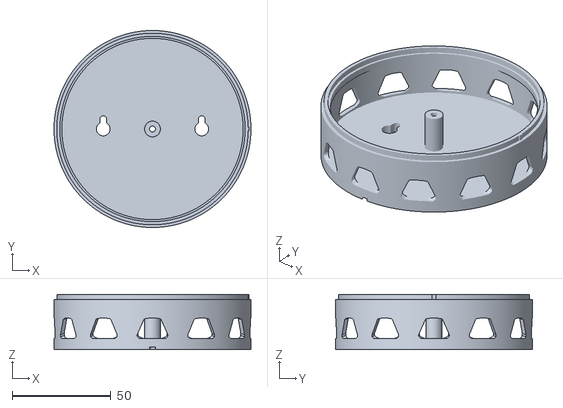
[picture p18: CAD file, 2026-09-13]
output/standoff_tests/body_zero.stl
100.0 x 100.0 x 28.0

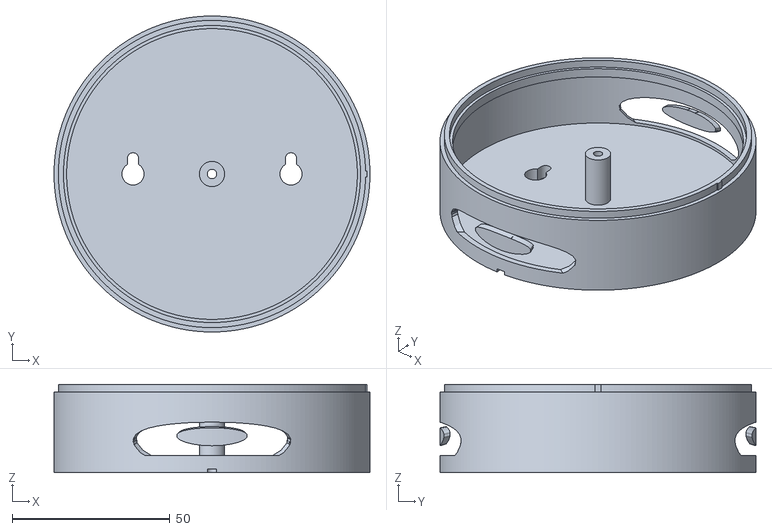
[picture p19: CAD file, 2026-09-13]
output/surface_smoke_preflight/body_0.stl
100.0 x 100.0 x 28.0

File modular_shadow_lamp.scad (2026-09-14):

// Modular shadow lamp — millimetres. Read README.md and OPTICS.md.
// Self-contained OpenSCAD 2021.01 / MakerWorld Parametric Model Maker.
// The wall is XY at z=0; +z points into the room. Filled SVG areas transmit light.

/* [View] */
Output = "Assembly"; // [Assembly,Projection,Body,Cover,Cover base,Cover artwork,Standoff,Print layout,Stack preview,Diagnostics]
Show_rays = false;
Show_report = true;
Cover_preview = "Exploded"; // [Exploded,Fitted,Hidden]
// Wall coordinates in mm: cylinder centre = (0,0), X right, Y up.
Show_grid = false;
Grid_spacing = 25; // [5:5:100]

/* [Artwork] */
// Automatic uses a changed file path first, then embedded artwork, then the demo.
// Choose SVG file explicitly if MakerWorld keeps the uploaded filename default.svg.
Artwork_source = "Automatic"; // [Automatic,SVG file,Built-in demo,Embedded artwork]
// MakerWorld recognizes this variable as an SVG upload control.
Svg_file = "default.svg";
// Which axis Shadow_length sets. Name the LONGER one, or the image is cropped square.
Svg_long_axis = "Y"; // [X,Y]
// Longest dimension of the complete artwork BEFORE central occlusion, in mm.
Shadow_length = 300; // [100:5:1500]
// Light shapes matches luminous outlines in the reference photo.
Artwork_mode = "Light shapes"; // [Light shapes,Dark silhouette]
// Small lit border around the dark silhouette field; avoids tangential, invalid cuts.
Dark_field_border = 3; // [0.5:0.5:20]
// Dark silhouette only: bound the lit field to a band round the shadow.
Light_limit = false;
// Same as shadow follows the outline; Circle and Rectangle wrap its bounding circle and box.
Light_limit_shape = "Same as shadow"; // [Same as shadow,Circle,Rectangle]
// Band width on the WALL, mm. Diagnostics reports the slot it opens in the shell.
Light_limit_thickness = 25; // [1:0.5:300]
// Bound the light OUTSIDE the artwork's silhouette.
Light_limit_outside = true;
// Off leaves an enclosed interior fully lit. NEEDS a prepared SVG or Interior_span below.
Light_limit_inside = true;
// Only used when the artwork carries no measured silhouette. Too small silently finds
// nothing, so the automatic value is Shadow_length: an enclosed area cannot be wider
// than the artwork itself, which makes it the one setting that can never under-fill.
// Widest enclosed area to treat as interior, mm. 0 = automatic (Shadow_length).
Interior_span = 0; // [0:5:1000]
Artwork_rotation = 0; // [-180:1:180]
Shadow_x = 0; // [-1000:1:1000]
Shadow_y = 0; // [-1000:1:1000]
// Smallest IMPORTANT line or gap, as % of the artwork's longest dimension.
// This is a declared design requirement, NOT an automatic SVG measurement.
Smallest_detail_percent = 5; // [0.1:0.1:20]

/* [Cylinder] */
Housing_shape = "Cylinder"; // [Cylinder,Rectangle]
Rectangle_width = 80; // [40:1:250]
Rectangle_depth = 100; // [40:1:250]
Cylinder_diameter = 100; // [60:1:250]
// Total closed depth of one module, including its fitted cover.
Cylinder_height = 30; // [18:0.5:200]
Wall_thickness = 2; // [1.2:0.1:4]
// 0 = first module at wall; 1 = second module, etc. Recompute each module.
Module_index = 0; // [0:1:8]

/* [LED and optical quality] */
LED_position = "Automatic"; // [Automatic,Manual height]
// Height of the EMITTING CENTRE above this module's back, not package bottom.
Manual_LED_height = 24; // [0:0.1:200]
// Width of the actual emitting area, not the plastic lens or LED package.
Emitter_diameter = 0.2; // [0:0.01:5]
// Axial thickness of the emitting area. 0 assumes a planar emitter parallel to wall.
Emitter_axial_depth = 0; // [0:0.01:2]
Maximum_blur = 2; // [0.1:0.1:20]
Minimum_cut_width = 0.4; // [0.15:0.05:2]
// Cut width and blur are print-quality judgements, not geometry: the part builds either
// way. Refuse restores the old behaviour of blocking the export when they are missed.
Quality_limits = "Warn"; // [Warn,Refuse]
// Emitting centre above the end of the printed pillar; measure your LED assembly.
Emitter_above_pillar = 3; // [1:0.1:10]
Pillar_diameter = 8; // [4:0.5:20]
// Continuous empty passage through the rear floor and the whole pillar, in mm.
Pillar_wire_bore = 3; // [1:0.1:6]

/* [Stencil supports] */
// Spokes interrupt light but can connect otherwise floating opaque islands.
// They do NOT guarantee connectivity for arbitrary artwork; run prepare_svg.py.
Support_bridges = true;
Support_layout = "Radial"; // [Radial,Manual XY,Radial and XY]
Bridge_count = 12; // [3:1:48]
Bridge_width = 0.8; // [0.4:0.1:2]
Bridge_rotation = 15; // [0:1:180]
// Helper mode disables the regular spokes and retains only mesh-detected repairs.
Automatic_bridges_only = false;
// Simplify narrow opaque strips in wall space using a conservative shell scale.
// 0 preserves the original geometry. This changes the shadow; inspect Projection.
Minimum_web_width = 0; // [0:0.1:2]

/* [Manual XY supports] */
// Segments are specified on the WALL grid. Width is the dark strip width on the wall.
// Enable Manual XY or Radial and XY in Support_layout to use these segments.
Support_1_enabled = true;
Support_1_start = [0,0];
Support_1_end = [0,200];
Support_1_width = 8; // [0.5:0.5:50]
Support_2_enabled = false;
Support_2_start = [0,0];
Support_2_end = [200,0];
Support_2_width = 8; // [0.5:0.5:50]
Support_3_enabled = false;
Support_3_start = [0,0];
Support_3_end = [0,-200];
Support_3_width = 8; // [0.5:0.5:50]
Support_4_enabled = false;
Support_4_start = [0,0];
Support_4_end = [-200,0];
Support_4_width = 8; // [0.5:0.5:50]

/* [Cover artwork and wiring] */
// White FLUSH inlay on the outward-facing circular cover; independent of shadow SVG.
Cover_artwork_source = "Automatic"; // [Automatic,None,SVG file,Embedded artwork]
Cover_svg_file = "default.svg";
Cover_svg_long_axis = "Y"; // [X,Y]
Cover_artwork_length = 65; // [5:1:240]
Cover_artwork_rotation = 0; // [-180:1:180]
Cover_artwork_depth = 0.6; // [0.2:0.1:1.2]
// Centre hole through both cover and inlay. Zero means a closed cover.
Cover_hole_diameter = 0; // [0:0.1:20]

/* [Mounting] */
// A standoff lifts the source, so the image grows -- and so does the hidden centre.
// Gap between the room wall and this module's back, mm. 0 = flush. Holds the electronics.
Wall_standoff = 0; // [0:0.5:200]
// Separate ring prints the gap as its own part; Extended body grows the body backwards.
Standoff_mode = "Separate ring"; // [Separate ring,Extended body]
// Back plate of the compartment. It carries the keyholes and the cable route.
Standoff_back = 3; // [1.5:0.1:8]

/* [Joints and cover] */
Joint_depth = 2.5; // [1.5:0.1:4]
Joint_clearance = 0.2; // [0.1:0.05:0.4]
Cover_plate = 2; // [1.5:0.1:3]
// Radial pilot holes in female collars for optional retaining screws.
Retaining_screws = true;
Screw_pilot_diameter = 2.1; // [1.5:0.1:3]

/* [Quality] */
Cylinder_facets = 180; // [72:12:360]

/* [Hidden] */
// Compatibility with older saved presets; Artwork_source overrides this control.
Use_svg = false;
$fn = Cylinder_facets;
eps = 0.02;
// prepare_svg.py replaces this block with normalized, embedded SVG geometry.
Embedded_artwork = false;
Embedded_radius_factor = 0.7071067811865476;
// Artwork width and height as fractions of its longest side; the longer one is 1.
// Only the helper can measure this, so a directly imported SVG falls back to a square.
Embedded_extent = [1,1];
// The artwork's silhouette: its outermost contours with every hole filled in. Only the
// helper can work out which contours are holes, so a direct SVG import has none.
Embedded_outline = false;
// BEGIN ARTWORK SILHOUETTE
module embedded_artwork_outline() { square(1,center=true); }
// END ARTWORK SILHOUETTE
// Extra bridge angles added by the helper after checking the actual exported mesh.
Embedded_bridge_angles = [];
// [angle, local top Z] vertical ribs added only as far as a floating island.
Embedded_bridge_segments = [];
Embedded_removed_islands = [];
Embedded_surface_repair = false;
Embedded_surface_signature = [];
// BEGIN EMBEDDED PRINT LIGHT
module embedded_print_light() {}
// END EMBEDDED PRINT LIGHT
// BEGIN EMBEDDED ARTWORK
module embedded_artwork() { square(1,center=true); }
// END EMBEDDED ARTWORK
Embedded_cover_artwork = false;
// BEGIN EMBEDDED COVER ARTWORK
module embedded_cover_artwork() { square(1, center=true); }
// END EMBEDDED COVER ARTWORK
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

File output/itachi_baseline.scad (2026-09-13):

// Artwork is embedded. To replace it, select Artwork_source = SVG file, or rerun prepare_svg.py.
// Modular shadow lamp — millimetres. Read README.md and OPTICS.md.
// Self-contained OpenSCAD 2021.01 / MakerWorld Parametric Model Maker.
// The wall is XY at z=0; +z points into the room. Filled SVG areas transmit light.

/* [View] */
Output = "Assembly"; // [Assembly,Projection,Body,Cover,Cover base,Cover artwork,Standoff,Print layout,Stack preview,Diagnostics]
Show_rays = false;
Show_report = true;
Cover_preview = "Exploded"; // [Exploded,Fitted,Hidden]
// Wall coordinates in mm: cylinder centre = (0,0), X right, Y up.
Show_grid = false;
Grid_spacing = 25; // [5:5:100]

/* [Artwork] */
// Automatic uses a changed file path first, then embedded artwork, then the demo.
// Choose SVG file explicitly if MakerWorld keeps the uploaded filename default.svg.
Artwork_source = "Automatic"; // [Automatic,SVG file,Built-in demo,Embedded artwork]
// MakerWorld recognizes this variable as an SVG upload control.
Svg_file = "default.svg";
// Select the LONGER artwork axis. The other axis scales proportionally.
Svg_long_axis = "Y"; // [X,Y]
// Longest dimension of the complete artwork BEFORE central occlusion, in mm.
Shadow_length = 300; // [100:5:1500]
// Light shapes matches luminous outlines in the reference photo.
Artwork_mode = "Light shapes"; // [Light shapes,Dark silhouette]
// Small lit border around the dark silhouette field; avoids tangential, invalid cuts.
Dark_field_border = 3; // [0.5:0.5:20]
Artwork_rotation = 0; // [-180:1:180]
Shadow_x = 0; // [-1000:1:1000]
Shadow_y = 0; // [-1000:1:1000]
// Smallest IMPORTANT line or gap, as % of the artwork's longest dimension.
// This is a declared design requirement, NOT an automatic SVG measurement.
Smallest_detail_percent = 5; // [0.1:0.1:20]

/* [Cylinder] */
Cylinder_diameter = 100; // [60:1:250]
// Total closed depth of one module, including its fitted cover.
Cylinder_height = 30; // [18:0.5:200]
Wall_thickness = 2; // [1.2:0.1:4]
// 0 = first module at wall; 1 = second module, etc. Recompute each module.
Module_index = 0; // [0:1:8]

/* [LED and optical quality] */
LED_position = "Automatic"; // [Automatic,Manual height]
// Height of the EMITTING CENTRE above this module's back, not package bottom.
Manual_LED_height = 24; // [0:0.1:200]
// Width of the actual emitting area, not the plastic lens or LED package.
Emitter_diameter = 0.2; // [0:0.01:5]
// Axial thickness of the emitting area. 0 assumes a planar emitter parallel to wall.
Emitter_axial_depth = 0; // [0:0.01:2]
Maximum_blur = 2; // [0.1:0.1:20]
Minimum_cut_width = 0.4; // [0.15:0.05:2]
// Emitting centre above the end of the printed pillar; measure your LED assembly.
Emitter_above_pillar = 3; // [1:0.1:10]
Pillar_diameter = 8; // [4:0.5:20]
// Continuous empty passage through the rear floor and the whole pillar, in mm.
Pillar_wire_bore = 3; // [1:0.1:6]

/* [Stencil supports] */
// Spokes interrupt light but can connect otherwise floating opaque islands.
// They do NOT guarantee connectivity for arbitrary artwork; run prepare_svg.py.
Support_bridges = true;
Support_layout = "Radial"; // [Radial,Manual XY,Radial and XY]
Bridge_count = 12; // [3:1:48]
Bridge_width = 0.8; // [0.4:0.1:2]
Bridge_rotation = 15; // [0:1:180]

/* [Manual XY supports] */
// Segments are specified on the WALL grid. Width is the dark strip width on the wall.
// Enable Manual XY or Radial and XY in Support_layout to use these segments.
Support_1_enabled = true;
Support_1_start = [0,0];
Support_1_end = [0,200];
Support_1_width = 8; // [0.5:0.5:50]
Support_2_enabled = false;
Support_2_start = [0,0];
Support_2_end = [200,0];
Support_2_width = 8; // [0.5:0.5:50]
Support_3_enabled = false;
Support_3_start = [0,0];
Support_3_end = [0,-200];
Support_3_width = 8; // [0.5:0.5:50]
Support_4_enabled = false;
Support_4_start = [0,0];
Support_4_end = [-200,0];
Support_4_width = 8; // [0.5:0.5:50]

/* [Cover artwork and wiring] */
// White FLUSH inlay on the outward-facing circular cover; independent of shadow SVG.
Cover_artwork_source = "Automatic"; // [Automatic,None,SVG file,Embedded artwork]
Cover_svg_file = "default.svg";
Cover_svg_long_axis = "Y"; // [X,Y]
Cover_artwork_length = 65; // [5:1:240]
Cover_artwork_rotation = 0; // [-180:1:180]
Cover_artwork_depth = 0.6; // [0.2:0.1:1.2]
// Centre hole through both cover and inlay. Zero means a closed cover.
Cover_hole_diameter = 0; // [0:0.1:20]

/* [Mounting] */
// Clear gap held between the room wall and this module's back. 0 = flush to the wall.
// The gap is a closed compartment for the electronics. A standoff lifts the source,
// so the reachable image grows -- but the hidden centre widens at a similar rate.
Wall_standoff = 0; // [0:0.5:200]
// Separate ring prints the gap as its own part that plugs into the rear socket.
// Extended body grows the body backwards instead, as one piece with no extra joint.
Standoff_mode = "Separate ring"; // [Separate ring,Extended body]
// Back plate of the compartment. It carries the keyholes and the cable route.
Standoff_back = 3; // [1.5:0.1:8]

/* [Joints and cover] */
Joint_depth = 2.5; // [1.5:0.1:4]
Joint_clearance = 0.2; // [0.1:0.05:0.4]
Cover_plate = 2; // [1.5:0.1:3]
// Radial pilot holes in female collars for optional retaining screws.
Retaining_screws = true;
Screw_pilot_diameter = 2.1; // [1.5:0.1:3]

/* [Quality] */
Cylinder_facets = 180; // [72:12:360]
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

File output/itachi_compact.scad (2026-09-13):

// Artwork is embedded. To replace it, select Artwork_source = SVG file, or rerun prepare_svg.py.
// Modular shadow lamp — millimetres. Read README.md and OPTICS.md.
// Self-contained OpenSCAD 2021.01 / MakerWorld Parametric Model Maker.
// The wall is XY at z=0; +z points into the room. Filled SVG areas transmit light.

/* [View] */
Output = "Assembly"; // [Assembly,Projection,Body,Cover,Cover base,Cover artwork,Standoff,Print layout,Stack preview,Diagnostics]
Show_rays = false;
Show_report = true;
Cover_preview = "Exploded"; // [Exploded,Fitted,Hidden]
// Wall coordinates in mm: cylinder centre = (0,0), X right, Y up.
Show_grid = false;
Grid_spacing = 25; // [5:5:100]

/* [Artwork] */
// Automatic uses a changed file path first, then embedded artwork, then the demo.
// Choose SVG file explicitly if MakerWorld keeps the uploaded filename default.svg.
Artwork_source = "Automatic"; // [Automatic,SVG file,Built-in demo,Embedded artwork]
// MakerWorld recognizes this variable as an SVG upload control.
Svg_file = "default.svg";
// Select the LONGER artwork axis. The other axis scales proportionally.
Svg_long_axis = "Y"; // [X,Y]
// Longest dimension of the complete artwork BEFORE central occlusion, in mm.
Shadow_length = 600.0; // [100:5:1500]
// Light shapes matches luminous outlines in the reference photo.
Artwork_mode = "Light shapes"; // [Light shapes,Dark silhouette]
// Small lit border around the dark silhouette field; avoids tangential, invalid cuts.
Dark_field_border = 3; // [0.5:0.5:20]
Artwork_rotation = 0; // [-180:1:180]
Shadow_x = 0; // [-1000:1:1000]
Shadow_y = 0; // [-1000:1:1000]
// Smallest IMPORTANT line or gap, as % of the artwork's longest dimension.
// This is a declared design requirement, NOT an automatic SVG measurement.
Smallest_detail_percent = 5; // [0.1:0.1:20]

/* [Cylinder] */
Housing_shape = "Cylinder"; // [Cylinder,Rectangle]
Rectangle_width = 80; // [40:1:250]
Rectangle_depth = 100; // [40:1:250]
Cylinder_diameter = 80.0; // [60:1:250]
// Total closed depth of one module, including its fitted cover.
Cylinder_height = 30.0; // [18:0.5:200]
Wall_thickness = 2; // [1.2:0.1:4]
// 0 = first module at wall; 1 = second module, etc. Recompute each module.
Module_index = 0; // [0:1:8]

/* [LED and optical quality] */
LED_position = "Automatic"; // [Automatic,Manual height]
// Height of the EMITTING CENTRE above this module's back, not package bottom.
Manual_LED_height = 24; // [0:0.1:200]
// Width of the actual emitting area, not the plastic lens or LED package.
Emitter_diameter = 0.2; // [0:0.01:5]
// Axial thickness of the emitting area. 0 assumes a planar emitter parallel to wall.
Emitter_axial_depth = 0; // [0:0.01:2]
Maximum_blur = 2; // [0.1:0.1:20]
Minimum_cut_width = 0.4; // [0.15:0.05:2]
// Emitting centre above the end of the printed pillar; measure your LED assembly.
Emitter_above_pillar = 3; // [1:0.1:10]
Pillar_diameter = 8; // [4:0.5:20]
// Continuous empty passage through the rear floor and the whole pillar, in mm.
Pillar_wire_bore = 3; // [1:0.1:6]

/* [Stencil supports] */
// Spokes interrupt light but can connect otherwise floating opaque islands.
// They do NOT guarantee connectivity for arbitrary artwork; run prepare_svg.py.
Support_bridges = true;
Support_layout = "Radial"; // [Radial,Manual XY,Radial and XY]
Bridge_count = 12; // [3:1:48]
Bridge_width = 0.9; // [0.4:0.1:2]
Bridge_rotation = 15; // [0:1:180]
// Helper mode disables the regular spokes and retains only mesh-detected repairs.
Automatic_bridges_only = true;
// Reinforce narrow opaque strips in wall space using a conservative shell scale.
// 0 preserves the original geometry. This changes the shadow; inspect Projection.
Minimum_web_width = 0.6; // [0:0.1:2]

/* [Manual XY supports] */
// Segments are specified on the WALL grid. Width is the dark strip width on the wall.
// Enable Manual XY or Radial and XY in Support_layout to use these segments.
Support_1_enabled = true;
Support_1_start = [0,0];
Support_1_end = [0,200];
Support_1_width = 8; // [0.5:0.5:50]
Support_2_enabled = false;
Support_2_start = [0,0];
Support_2_end = [200,0];
Support_2_width = 8; // [0.5:0.5:50]
Support_3_enabled = false;
Support_3_start = [0,0];
Support_3_end = [0,-200];
Support_3_width = 8; // [0.5:0.5:50]
Support_4_enabled = false;
Support_4_start = [0,0];
Support_4_end = [-200,0];
Support_4_width = 8; // [0.5:0.5:50]

/* [Cover artwork and wiring] */
// White FLUSH inlay on the outward-facing circular cover; independent of shadow SVG.
Cover_artwork_source = "Automatic"; // [Automatic,None,SVG file,Embedded artwork]
Cover_svg_file = "default.svg";
Cover_svg_long_axis = "Y"; // [X,Y]
Cover_artwork_length = 65; // [5:1:240]
Cover_artwork_rotation = 0; // [-180:1:180]
Cover_artwork_depth = 0.6; // [0.2:0.1:1.2]
// Centre hole through both cover and inlay. Zero means a closed cover.
Cover_hole_diameter = 0; // [0:0.1:20]

/* [Mounting] */
// Clear gap held between the room wall and this module's back. 0 = flush to the wall.
// The gap is a closed compartment for the electronics. A standoff lifts the source,
// so the reachable image grows -- but the hidden centre widens at a similar rate.
Wall_standoff = 30.0; // [0:0.5:200]
// Separate ring prints the gap as its own part that plugs into the rear socket.
// Extended body grows the body backwards instead, as one piece with no extra joint.
Standoff_mode = "Separate ring"; // [Separate ring,Extended body]
// Back plate of the compartment. It carries the keyholes and the cable route.
Standoff_back = 3; // [1.5:0.1:8]

/* [Joints and cover] */
Joint_depth = 2.5; // [1.5:0.1:4]
Joint_clearance = 0.2; // [0.1:0.05:0.4]
Cover_plate = 2; // [1.5:0.1:3]
// Radial pilot holes in female collars for optional retaining screws.
Retaining_screws = true;
Screw_pilot_diameter = 2.1; // [1.5:0.1:3]

/* [Quality] */
Cylinder_facets = 180; // [72:12:360]
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

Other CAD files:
output/itachi_surface_preflight/body_0.stl
output/monza_final_preflight/body_0.stl
output/monza_refined_preflight/body_0.stl
output/monza_surface_preflight/body_0.stl
output/itachi_balanced.scad
output/demo_body.stl
output/demo_cover.stl
output/features_demo.scad
output/features_demo.stl
output/features_demo_cover_artwork.stl
output/features_demo_cover_base.stl
output/features_demo_preflight/body_0.stl
output/features_demo_preflight/cover_artwork.stl
output/features_demo_preflight/cover_base.stl
output/features_demo_preflight/import_cover.scad
output/housing_tests/rectangle_body.scad
output/housing_tests/rectangle_body.stl
output/housing_tests/rectangle_cover.scad
output/housing_tests/rectangle_joints.scad
output/housing_tests/rectangle_ring.scad
output/housing_tests/rectangle_ring.stl
output/housing_tests/rib.scad
output/housing_tests/roundoff.stl
output/housing_tests/stale.scad
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

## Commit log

2026-09-13 project update
    [body_0.stl, body_1.stl, body_extended.stl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]
2026-09-14 less impossible generation constraints
    [modular_shadow_lamp.scad]
